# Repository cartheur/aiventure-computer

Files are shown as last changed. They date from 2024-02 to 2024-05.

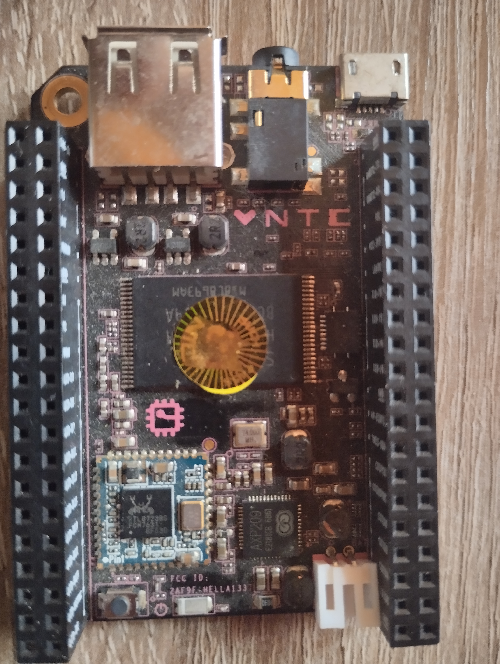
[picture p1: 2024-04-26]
chip_1_0/images/v1.0-top.jpg

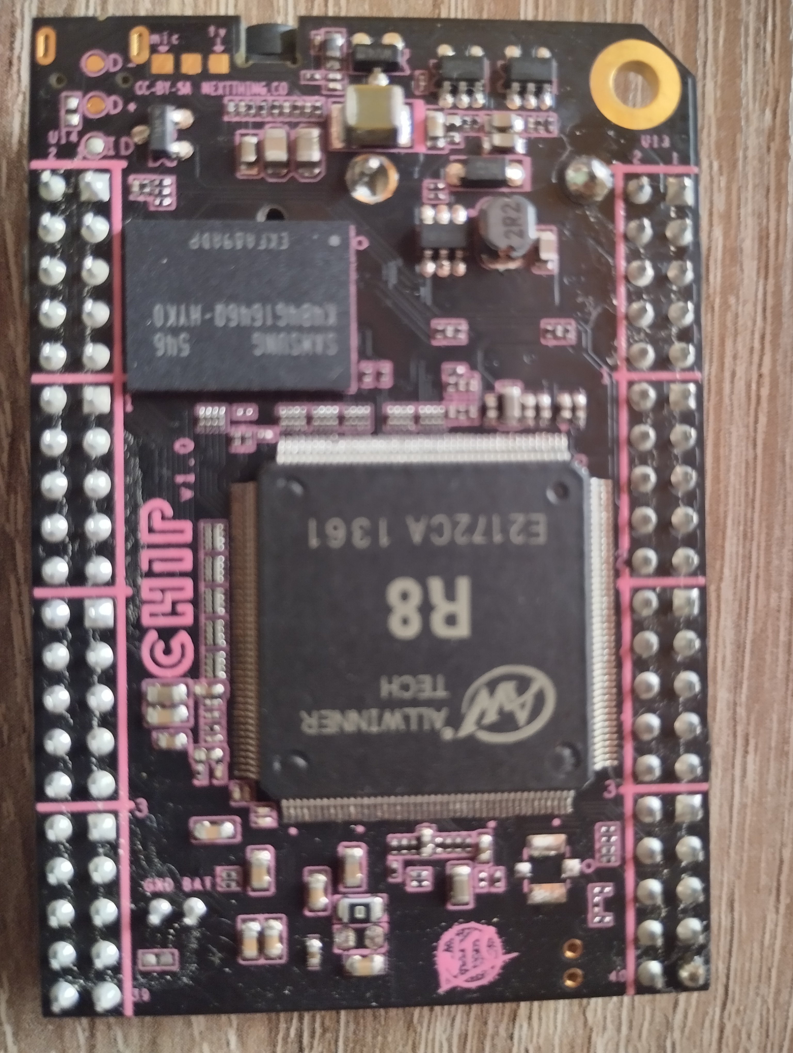
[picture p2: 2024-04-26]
chip_1_0/images/v1.0-bottom.jpg

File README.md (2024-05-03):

## aiventure-computer

The computer that currently runs our robotics platforms. As finding a replacement has been problematic for new development, can we evolve the design toward a manifestation of an aeon-class machine?

_Project Goals_

This board needs to be put into production to support [emotional](https://emotional.toys) toys products. The following changes need to be considered so that this board is brought-up to the current (2024) technological standards. The existing feature set and design experiences are listed [here](/chip_1_0/README.md).

* CPU/GPU - ARM Cortex-R82
* RAM (SDRAM) - 16 GB
    - Product tiers: 32GB, 64GB, 128GB. 256GB, 512GB 1TB
* NAND (100k writes)- 256 GB
* Pin interfaces at board level (no headers) (Requirement)
* Rechargable feature for JST connected battery retained but which allows higher-capacity batteries (Requirement)
* USB-C power, USB-B keyboard connectivity
* JST 3.5mm port 

Features nearly set for second-generation design. Getting ready.

## The target

* The target OS for the new design is Debian 12 (bookworm) with Linux kernel 6.6.23. The last kernel for the old board is version 4.4.13 according to `b149`. 
* The entire board will have to be proofed in order to obtain a rather assured estimate of the costs-per-unit of manufacture.

## The source

* The _project_ directory contains the correct <a href="http://www.orcad.com/" target="_blank">OrCAD</a> file. However, it seems to be missing footprints. They are found as a *.lbr file, which is for <a href="https://www.autodesk.com/products/eagle/free-download" target="_blank">Eagle</a>.
* It needs to be understood if the file can be opened in Altium and revised that a developer can use KiCad or EasyEDA.
* The milestone is to understand the current status and what needs to be done to prepare it for manufacturing of 500 units planned.

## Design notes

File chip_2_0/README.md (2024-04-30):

## Chip - Revision 2.0 (2024)

We are working toward a new experimental production run of this board and this folder contains the working files. Our goals will be:

* To pivot away from OrCad in favor of more accessible CAD tools
* Bring current the 2016-era components
* Produce a limited run where we will
    - Update the OS image to Debian Linux kernel 6.x
    - Introduce an autonomous ideal platform
    - Re-engineer the pin header
    - Render a different use-case for the features

### Results from analysis of current design (1.0)

Since transforming the design from OrCad to Altium, progress has been made to reveal each of the current feature-set, for import into the new production.

* The CPU is an ARM cortex8 R8 chip. It is a mid-range processor for use in deep-embedded, real time systems.
* The power management IC is APX209 which    accepts a battery and outputs several DC outputs.
* The three regulators are LP6226 which produce the 5v, 3.3v and 1.6v.
* The design contains two 40 pin LCDs. The LCDs part numbers are not defined. One of the LCDs is placed at the right side of the board and the other one is placed at the left side. Only the connectors of the LCDs can be seen in the boards.
    - The LCDs should be selected separately or According to the pinouts  of the connectors.
* There is also a remote I2C Bus expander in the design (PCF8574)
    -  In the original product there was a hat that had both banks of 40-pin headers where one could use a VGA or HDMI version to connect to an external monitor.
* There is a Bluetooth IC (8723BS) with an antenna in the board to communicate with  other devices via Bluetooth.
* To increase the addressable memory size, the design must implement the Cortex-R82 processor. It is 64-bit, 40 address bits which supports addressable memory up to 1TB.

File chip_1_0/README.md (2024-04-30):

## CHIP v1.0 Feature-Set

Features implemented on this model:

* Built-in Wi-Fi 802.11b/g/n, Bluetooth 4.0
* One USB host with type-A receptacle, one USB On-The-Go port
* Composite video and stereo audio port via mini TRRS
* Optional composite TRRS to RCA audio-video cable
* Optional VGA adapter and HDMI adapter (see Hardware extensions below)
* Open source hardware and open source software
* Unfortunately, the OrCad is _not_ open source
* Up to 45 GPIO ports
* Supports 1-Wire and I2C protocols, PWM output
* Serial console and Ethernet via USB for quick headless operation
* Power options include 5V via USB OTG, 5V via CHN pin, and by 3.7V battery
* Onboard NAND storage, 4-8 GB, pre-installed Linux OS (Debian)
* API-based firmware update
* The board is 60mm × 40mm x 15mm in size.
* The total addressable memory for the Cortex-R8 processor is 4GB.

_Analysis results_

* The schematic illustrated a number of errors which needed to be fixed. There are a multiple of errors in the pcb.
* The solution is to produce this board without any changes, but with the bugs sorted. After a round of manufacturing and software installation, resolve newly appearing bugs as a part of development of the second version that contains the updated requirements.

### Strategic initiatives

* To streamline the design process, the first version of the board is designed with Cortex-R8 and after implementing and manufacturing this version of project, increment the design to the Cortex-R82 in the second version.

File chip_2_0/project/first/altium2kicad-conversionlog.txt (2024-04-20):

Archive:  db/36068.zip
  inflating: db/36068/01 REVISION HISTORY.SchDoc  
  inflating: db/36068/02 BLOCK.SchDoc  
  inflating: db/36068/03 CPU.SchDoc  
  inflating: db/36068/04 POWER.SchDoc  
  inflating: db/36068/05 MISC.SchDoc  
  inflating: db/36068/06 SDIO WIFI&BT.SchDoc  
  inflating: db/36068/07 USB.SchDoc  
  inflating: db/36068/08 BESIDE CPU.SchDoc  
  inflating: db/36068/09 DDR3.SchDoc  
  inflating: db/36068/CHIP_v1_0.LOG  
  inflating: db/36068/CHIP_v1_0.PrjPcb  
  inflating: db/36068/CHIP_v1_0.PrjPcbStructure  
  inflating: db/36068/CHIP_v1_0_Library.SchLib  
  inflating: db/36068/01 REVISION HISTORY.~(1).SchDoc.Zip  
  inflating: db/36068/01 REVISION HISTORY.~(2).SchDoc.Zip  
  inflating: db/36068/02 BLOCK.~(1).SchDoc.Zip  
  inflating: db/36068/02 BLOCK.~(2).SchDoc.Zip  
  inflating: db/36068/03 CPU.~(1).SchDoc.Zip  
  inflating: db/36068/03 CPU.~(2).SchDoc.Zip  
  inflating: db/36068/04 POWER.~(1).SchDoc.Zip  
  inflating: db/36068/04 POWER.~(2).SchDoc.Zip  
  inflating: db/36068/05 MISC.~(1).SchDoc.Zip  
  inflating: db/36068/05 MISC.~(2).SchDoc.Zip  
  inflating: db/36068/06 SDIO WIFI&BT.~(1).SchDoc.Zip  
  inflating: db/36068/06 SDIO WIFI&BT.~(2).SchDoc.Zip  
  inflating: db/36068/07 USB.~(1).SchDoc.Zip  
  inflating: db/36068/07 USB.~(2).SchDoc.Zip  
  inflating: db/36068/08 BESIDE CPU.~(1).SchDoc.Zip  
  inflating: db/36068/08 BESIDE CPU.~(2).SchDoc.Zip  
  inflating: db/36068/09 DDR3.~(1).SchDoc.Zip  
  inflating: db/36068/09 DDR3.~(2).SchDoc.Zip  
  inflating: db/36068/CHIP_v1_0.~(1).PrjPcb.Zip  
  inflating: db/36068/CHIP_v1_0_Library.~(1).SchLib.Zip  
  inflating: db/36068/CHIP_v1_0_Library.~(2).SchLib.Zip  
  inflating: db/36068/CHIP_v1_0_Library.~(3).SchLib.Zip  
  inflating: db/36068/01 REVISION HISTORY.SchDocPreview  
  inflating: db/36068/02 BLOCK.SchDocPreview  
  inflating: db/36068/03 CPU.SchDocPreview  
  inflating: db/36068/04 POWER.SchDocPreview  
  inflating: db/36068/05 MISC.SchDocPreview  
  inflating: db/36068/06 SDIO WIFI&BT.SchDocPreview  
  inflating: db/36068/07 USB.SchDocPreview  
  inflating: db/36068/08 BESIDE CPU.SchDocPreview  
  inflating: db/36068/09 DDR3.SchDocPreview  
  inflating: db/36068/CHIP_v1_0.LOGPreview  
Loading 01 REVISION HISTORY.SchDoc

Loading 02 BLOCK.SchDoc

Loading 03 CPU.SchDoc

Loading 04 POWER.SchDoc

Loading 05 MISC.SchDoc

Loading 06 SDIO WIFI&BT.SchDoc

Loading 07 USB.SchDoc

Loading 08 BESIDE CPU.SchDoc

Loading 09 DDR3.SchDoc

Loading CHIP_v1_0_Library.SchLib

Done.
No unpacked .PcbDoc documents found. Trying to unpack it:
Loading 01 REVISION HISTORY.SchDoc

Loading 02 BLOCK.SchDoc

Loading 03 CPU.SchDoc

Loading 04 POWER.SchDoc

Loading 05 MISC.SchDoc

Loading 06 SDIO WIFI&BT.SchDoc

Loading 07 USB.SchDoc

Loading 08 BESIDE CPU.SchDoc

Loading 09 DDR3.SchDoc

Loading CHIP_v1_0_Library.SchLib

Done.
There were no unpacked PcbDoc files found.
Handling 01 REVISION HISTORY-SchDoc/Root Entry/FileHeader.dat
Unhandled Record type within: 30
Handling 02 BLOCK-SchDoc/Root Entry/FileHeader.dat
Unhandled Record type within: 30
Unhandled Record type without: 7  (#91)
Handling 03 CPU-SchDoc/Root Entry/FileHeader.dat
Unhandled Record type within: 30
Unhandled Record type within: 34
Unhandled Record type within: 34
Unhandled Record type within: 34
Unhandled Record type within: 34
Unhandled Record type within: 34
Unhandled Record type within: 34
Unhandled Record type within: 34
Unhandled Record type within: 34
Handling 04 POWER-SchDoc/Root Entry/FileHeader.dat
Unhandled Record type within: 30
Unhandled Record type within: 34
Unhandled Record type within: 34
Unhandled Record type within: 34
Unhandled Record type within: 34
Unhandled Record type within: 34
Unhandled Record type within: 34
Unhandled Record type within: 34
Unhandled Record type within: 34
Unhandled Record type within: 34
Unhandled Record type within: 34
Unhandled Record type within: 34
Unhandled Record type within: 34
Unhandled Record type within: 34
WARNING: Elliptical arcs are not supported in KiCad - creating circular arc using average radius instead
WARNING: Elliptical arcs are not supported in KiCad - creating circular arc using average radius instead
WARNING: Elliptical arcs are not supported in KiCad - creating circular arc using average radius instead
WARNING: Elliptical arcs are not supported in KiCad - creating circular arc using average radius instead
WARNING: Elliptical arcs are not supported in KiCad - creating circular arc using average radius instead
WARNING: Elliptical arcs are not supported in KiCad - creating circular arc using average radius instead
WARNING: Elliptical arcs are not supported in KiCad - creating circular arc using average radius instead
WARNING: Elliptical arcs are not supported in KiCad - creating circular arc using average radius instead
Unhandled Record type within: 34
Unhandled Record type within: 34
Unhandled Record type within: 34
WARNING: Elliptical arcs are not supported in KiCad - creating circular arc using average radius instead
WARNING: Elliptical arcs are not supported in KiCad - creating circular arc using average radius instead
WARNING: Elliptical arcs are not supported in KiCad - creating circular arc using average radius instead
WARNING: Elliptical arcs are not supported in KiCad - creating circular arc using average radius instead
WARNING: Elliptical arcs are not supported in KiCad - creating circular arc using average radius instead
WARNING: Elliptical arcs are not supported in KiCad - creating circular arc using average radius instead
WARNING: Elliptical arcs are not supported in KiCad - creating circular arc using average radius instead
WARNING: Elliptical arcs are not supported in KiCad - creating circular arc using average radius instead
Unhandled Record type within: 34
Unhandled Record type within: 34
Unhandled Record type within: 34
Unhandled Record type within: 34
Unhandled Record type within: 34
Unhandled Record type within: 34
Unhandled Record type within: 34
Unhandled Record type within: 34
Unhandled Record type within: 34
Unhandled Record type within: 34
Unhandled Record type within: 34
Unhandled Record type within: 34
Unhandled Record type within: 34
Unhandled Record type within: 34
Unhandled Record type within: 34
Unhandled Record type within: 34
Unhandled Record type within: 34
Unhandled Record type within: 34
Unhandled Record type within: 34
Unhandled Record type within: 34
WARNING: Elliptical arcs are not supported in KiCad - creating circular arc using average radius instead
WARNING: Elliptical arcs are not supported in KiCad - creating circular arc using average radius instead
WARNING: Elliptical arcs are not supported in KiCad - creating circular arc using average radius instead
WARNING: Elliptical arcs are not supported in KiCad - creating circular arc using average radius instead
WARNING: Elliptical arcs are not supported in KiCad - creating circular arc using average radius instead
WARNING: Elliptical arcs are not supported in KiCad - creating circular arc using average radius instead
WARNING: Elliptical arcs are not supported in KiCad - creating circular arc using average radius instead
WARNING: Elliptical arcs are not supported in KiCad - creating circular arc using average radius instead
Unhandled Record type within: 34
Unhandled Record type within: 34
Unhandled Record type within: 34
Unhandled Record type within: 34
Unhandled Record type within: 34
Unhandled Record type within: 34
Unhandled Record type within: 34
Unhandled Record type within: 34
Unhandled Record type within: 34
Unhandled Record type within: 34
Unhandled Record type within: 34
Unhandled Record type within: 34
Unhandled Record type within: 34
WARNING: Elliptical arcs are not supported in KiCad - creating circular arc using average radius instead
WARNING: Elliptical arcs are not supported in KiCad - creating circular arc using average radius instead
WARNING: Elliptical arcs are not supported in KiCad - creating circular arc using average radius instead
WARNING: Elliptical arcs are not supported in KiCad - creating circular arc using average radius instead
WARNING: Elliptical arcs are not supported in KiCad - creating circular arc using average radius instead
WARNING: Elliptical arcs are not supported in KiCad - creating circular arc using average radius instead
WARNING: Elliptical arcs are not supported in KiCad - creating circular arc using average radius instead
WARNING: Elliptical arcs are not supported in KiCad - creating circular arc using average radius instead
Unhandled Record type within: 34
Unhandled Record type within: 34
Unhandled Record type within: 34
Unhandled Record type within: 34
Unhandled Record type within: 34
Unhandled Record type within: 34
Unhandled Record type within: 34
Unhandled Record type within: 34
Unhandled Record type within: 34
Unhandled Record type within: 34
Unhandled Record type within: 34
Unhandled Record type within: 34
Unhandled Record type within: 34
Unhandled Record type within: 34
WARNING: Elliptical arcs are not supported in KiCad - creating circular arc using average radius instead
WARNING: Elliptical arcs are not supported in KiCad - creating circular arc using average radius instead
WARNING: Elliptical arcs are not supported in KiCad - creating circular arc using average radius instead
WARNING: Elliptical arcs are not supported in KiCad - creating circular arc using average radius instead
WARNING: Elliptical arcs are not supported in KiCad - creating circular arc using average radius instead
WARNING: Elliptical arcs are not supported in KiCad - creating circular arc using average radius instead
WARNING: Elliptical arcs are not supported in KiCad - creating circular arc using average radius instead
WARNING: Elliptical arcs are not supported in KiCad - creating circular arc using average radius instead
Unhandled Record type within: 34
Unhandled Record type within: 34
Unhandled Record type within: 34
Unhandled Record type within: 34
Unhandled Record type within: 34
WARNING: Elliptical arcs are not supported in KiCad - creating circular arc using average radius instead
WARNING: Elliptical arcs are not supported in KiCad - creating circular arc using average radius instead
WARNING: Elliptical arcs are not supported in KiCad - creating circular arc using average radius instead
WARNING: Elliptical arcs are not supported in KiCad - creating circular arc using average radius instead
WARNING: Elliptical arcs are not supported in KiCad - creating circular arc using average radius instead
WARNING: Elliptical arcs are not supported in KiCad - creating circular arc using average radius instead
WARNING: Elliptical arcs are not supported in KiCad - creating circular arc using average radius instead
WARNING: Elliptical arcs are not supported in KiCad - creating circular arc using average radius instead
Unhandled Record type within: 34
Unhandled Record type within: 34
Unhandled Record type within: 34
Unhandled Record type within: 34
Unhandled Record type within: 34
Unhandled Record type within: 34
Handling 05 MISC-SchDoc/Root Entry/FileHeader.dat
Unhandled Record type within: 30
Unhandled Record type within: 34
WARNING: Elliptical arcs are not supported in KiCad - creating circular arc using average radius instead
WARNING: Elliptical arcs are not supported in KiCad - creating circular arc using average radius instead
WARNING: Elliptical arcs are not supported in KiCad - creating circular arc using average radius instead
WARNING: Elliptical arcs are not supported in KiCad - creating circular arc using average radius instead
WARNING: Elliptical arcs are not supported in KiCad - creating circular arc using average radius instead
WARNING: Elliptical arcs are not supported in KiCad - creating circular arc using average radius instead
WARNING: Elliptical arcs are not supported in KiCad - creating circular arc using average radius instead
WARNING: Elliptical arcs are not supported in KiCad - creating circular arc using average radius instead
Unhandled Record type within: 34
Unhandled Record type within: 34
Unhandled Record type within: 34
Unhandled Record type within: 34
Unhandled Record type within: 34
Unhandled Record type within: 34
Unhandled Record type within: 34
Unhandled Record type within: 34
Unhandled Record type within: 34
Unhandled Record type within: 34
Unhandled Record type within: 34
Unhandled Record type within: 34
Unhandled Record type within: 34
Unhandled Record type within: 34
Unhandled Record type within: 34
Unhandled Record type within: 34
Unhandled Record type within: 34
Unhandled Record type within: 34
Unhandled Record type within: 34
Unhandled Record type within: 34
Unhandled Record type within: 34
Unhandled Record type within: 34
Unhandled Record type within: 34
Unhandled Record type within: 34
Unhandled Record type within: 34
Unhandled Record type within: 34
Unhandled Record type within: 34
Unhandled Record type within: 34
Unhandled Record type within: 34
Unhandled Record type within: 34
Unhandled Record type within: 34
Unhandled Record type within: 34
Unhandled Record type within: 34
Unhandled Record type within: 34
Unhandled Record type within: 34
Unhandled Record type within: 34
Unhandled Record type within: 34
Unhandled Record type within: 34
Unhandled Record type within: 34
Unhandled Record type within: 34
Unhandled Record type within: 34
Handling 06 SDIO WIFI&BT-SchDoc/Root Entry/FileHeader.dat
Unhandled Record type within: 30
Unhandled Record type within: 34
Unhandled Record type within: 34
Unhandled Record type within: 34
Unhandled Record type within: 34
Unhandled Record type within: 34
Unhandled Record type within: 34
Unhandled Record type within: 34
Unhandled Record type within: 34
Unhandled Record type within: 34
Unhandled Record type within: 34
Unhandled Record type within: 34
Unhandled Record type within: 34
Unhandled Record type within: 34
Unhandled Record type within: 34
Unhandled Record type within: 34
Unhandled Record type within: 34
Unhandled Record type within: 34
Unhandled Record type within: 34
Unhandled Record type within: 34
Unhandled Record type within: 34
Unhandled Record type within: 34
Unhandled Record type within: 34
Unhandled Record type within: 34
Unhandled Record type within: 34
Unhandled Record type within: 34
Unhandled Record type within: 34
Unhandled Record type within: 34
Unhandled Record type within: 34
Unhandled Record type within: 34
Unhandled Record type within: 34
Unhandled Record type within: 34
Handling 07 USB-SchDoc/Root Entry/FileHeader.dat
Unhandled Record type within: 30
Unhandled Record type within: 34
WARNING: Elliptical arcs are not supported in KiCad - creating circular arc using average radius instead
WARNING: Elliptical arcs are not supported in KiCad - creating circular arc using average radius instead
Unhandled Record type within: 34
Unhandled Record type within: 34
Unhandled Record type within: 34
Unhandled Record type within: 34
Unhandled Record type within: 34
Unhandled Record type within: 34
Unhandled Record type within: 34
Unhandled Record type within: 34
Unhandled Record type within: 34
Unhandled Record type within: 34
Unhandled Record type within: 34
Unhandled Record type within: 34
Unhandled Record type within: 34
Unhandled Record type within: 34
Unhandled Record type within: 34
Unhandled Record type within: 34
Unhandled Record type within: 34
Unhandled Record type within: 34
Unhandled Record type within: 34
Unhandled Record type within: 34
Unhandled Record type within: 34
Unhandled Record type within: 34
Unhandled Record type within: 34
Unhandled Record type within: 34
Unhandled Record type within: 34
Unhandled Record type within: 34
Handling 08 BESIDE CPU-SchDoc/Root Entry/FileHeader.dat
Unhandled Record type within: 30
Unhandled Record type within: 34
Unhandled Record type within: 34
Unhandled Record type within: 34
Unhandled Record type within: 34
Unhandled Record type within: 34
Unhandled Record type within: 34
Unhandled Record type within: 34
Unhandled Record type within: 34
Unhandled Record type within: 34
Unhandled Record type within: 34
Unhandled Record type within: 34
Unhandled Record type within: 34
Unhandled Record type within: 34
Unhandled Record type within: 34
Unhandled Record type within: 34
Unhandled Record type within: 34
Unhandled Record type within: 34
Unhandled Record type within: 34
Unhandled Record type within: 34
Unhandled Record type within: 34
Unhandled Record type within: 34
Unhandled Record type within: 34
Unhandled Record type within: 34
Unhandled Record type within: 34
Unhandled Record type within: 34
Unhandled Record type within: 34
Unhandled Record type within: 34
Unhandled Record type within: 34
Unhandled Record type within: 34
Unhandled Record type within: 34
Unhandled Record type within: 34
Unhandled Record type within: 34
Unhandled Record type within: 34
Unhandled Record type within: 34
Unhandled Record type within: 34
Unhandled Record type within: 34
Unhandled Record type within: 34
Unhandled Record type within: 34
Unhandled Record type within: 34
Unhandled Record type within: 34
Unhandled Record type within: 34
Unhandled Record type within: 34
Unhandled Record type within: 34
Unhandled Record type within: 34
Unhandled Record type within: 34
Unhandled Record type within: 34
Unhandled Record type within: 34
Unhandled Record type within: 34
Unhandled Record type within: 34
Unhandled Record type within: 34
Unhandled Record type within: 34
Unhandled Record type within: 34
Handling 09 DDR3-SchDoc/Root Entry/FileHeader.dat
Unhandled Record type within: 30
Unhandled Record type within: 34
Unhandled Record type within: 34
Unhandled Record type within: 34
Unhandled Record type within: 34
Unhandled Record type within: 34
Unhandled Record type within: 34
Unhandled Record type within: 34
Unhandled Record type within: 34
Unhandled Record type within: 34
Unhandled Record type within: 34
Unhandled Record type within: 34
Unhandled Record type within: 34
Unhandled Record type within: 34
Unhandled Record type within: 34
Unhandled Record type within: 34
Unhandled Record type within: 34
Unhandled Record type within: 34
Unhandled Record type within: 34
Unhandled Record type within: 34
Unhandled Record type within: 34
Unhandled Record type within: 34
Unhandled Record type within: 34
Unhandled Record type within: 34
Unhandled Record type within: 34
Unhandled Record type within: 34
Unhandled Record type within: 34
Unhandled Record type within: 34
Unhandled Record type within: 34
Unhandled Record type within: 34
Unhandled Record type within: 34
Unhandled Record type within: 34
Unhandled Record type within: 34
Unhandled Record type within: 34
Unhandled Record type within: 34
Unhandled Record type within: 34
Unhandled Record type within: 34
Unhandled Record type within: 34
Unhandled Record type within: 34
Unhandled Record type within: 34
Unhandled Record type within: 34
Unhandled Record type within: 34
Unhandled Record type within: 34
Unhandled Record type within: 34
Unhandled Record type within: 34
Unhandled Record type within: 34
Handling CHIP_v1_0_Library-SchLib/Root Entry/FileHeader.dat
Handling 01 REVISION HISTORY.SchDoc
Handling 02 BLOCK.SchDoc
Handling 03 CPU.SchDoc
Handling 04 POWER.SchDoc
Handling 05 MISC.SchDoc
Handling 06 SDIO WIFI&BT.SchDoc
Handling 07 USB.SchDoc
Handling 08 BESIDE CPU.SchDoc
Handling 09 DDR3.SchDoc

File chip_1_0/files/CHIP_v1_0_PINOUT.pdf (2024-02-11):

GND | 1 | 2 | CHG-IN | | GND | 1 | 2 | VCC-5V
VCC-5V | 3 | 4 | GND | | UART1-TX | 3 | 4 | HPL
VCC-3V3 | 5 | 6 | TS | | UART1-RX | 5 | 6 | HPCOM
VCC-1V8 | 7 | 8 | BAT | | FEL | 7 | 8 | HPR
TWI1-SDA | 9 | 10 | PWRON | was LRADC> | VCC-3V3 | 9 | 10 | MICM
TWI1-SCK | 11 | 12 | GND | was GND> | LRADC | 11 | 12 | MICIN1
X1 | 13 | 14 | X2 | | XIO-P0 | 13 | 14 | XIO-P1
Y1 | 15 | 16 | Y2 | | XIO-P2 | 15 | 16 | XIO-P3
LCD-D2 | 17 | 18 | PWM0 | | XIO-P4 | 17 | 18 | XIO-P5
LCD-D4 | 19 | 20 | LCD-D3 | | XIO-P6 | 19 | 20 | XIO-P7
LCD-D6 | 21 | 22 | LCD-D5 | | GND | 21 | 22 | GND
LCD-D10 | 23 | 24 | LCD-D7 | | AP-EINT1 | 23 | 24 | AP-EINT3
LCD-D12 | 25 | 26 | LCD-D11 | | TWI2-SDA | 25 | 26 | TWI2-SCK
LCD-D14 | 27 | 28 | LCD-D13 | | CSIPCK | 27 | 28 | CSICK
LCD-D18 | 29 | 30 | LCD-D15 | | CSIHSYNC | 29 | 30 | CSIVSYNC
LCD-D20 | 31 | 32 | LCD-D19 | | CSID0 | 31 | 32 | CSID1
LCD-D22 | 33 | 34 | LCD-D21 | | CSID2 | 33 | 34 | CSID3
LCD-CLK | 35 | 36 | LCD-D23 | | CSID4 | 35 | 36 | CSID5
LCD-VSYNC | 37 | 38 | LCD-HSYNC | | CSID6 | 37 | 38 | CSID7
GND | 39 | 40 | LCD-DE | | GND | 39 | 40 | GND

Use square pad

## C.H.I.P. (v1.0) PINOUT

U13 | U14

New Pin Location vs. v0.21

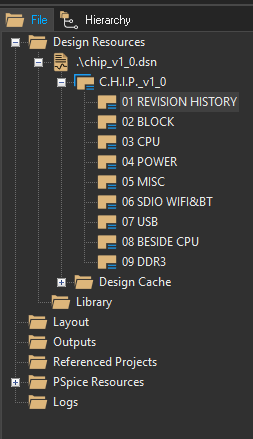
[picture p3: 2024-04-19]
chip_2_0/catalogue/design root/Design root.png

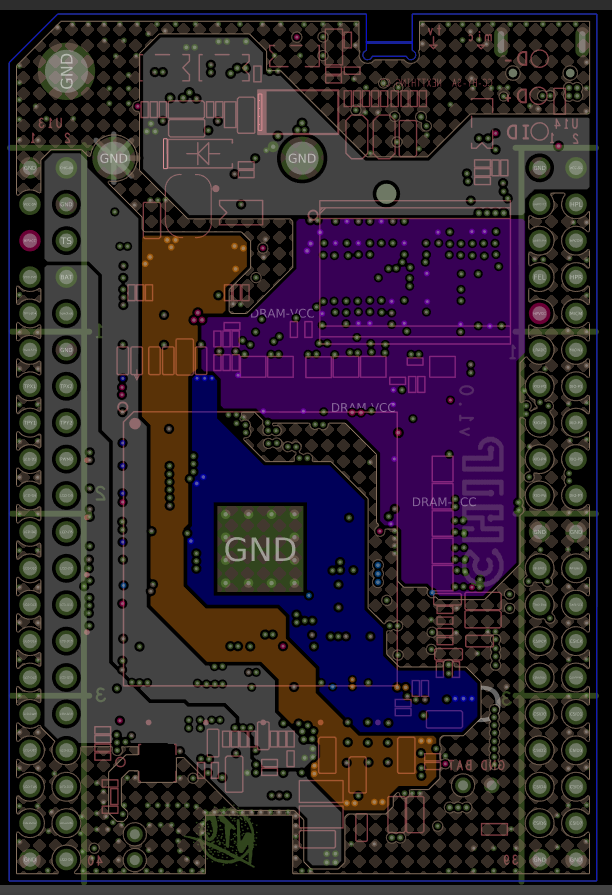
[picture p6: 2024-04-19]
chip_2_0/catalogue/PCB/Vcc layer.png

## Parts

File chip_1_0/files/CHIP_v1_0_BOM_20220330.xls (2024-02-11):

*********************************************************************************************************************************************
the cartheur company
docs.cartheur.ai
*********************************************************************************************************************************************
PCBA BOM
Model |  |  | C.H.I.P.
Version |  |  | v1.0
BOM Revision |  |  | V1_0_20220330
Date |  |  | 2022-03-30
 | Description | QTY(QPA) | Location(refernece) | Type(DIP/SMT)
1 | IC CPU R8 TQFP177 | 1 | U1 | SMT
2 | IC PMU AXP209 QFN49_0_4H0_8A | 1 | U3 | SMT
3 | IC IO EXTEND PCF8574ARGYR QFN20-PT0_5-3_65X4_65H1A | 1 | U27 | SMT
4 | IC CONTINUOUS CURRENT LPW5210 SOT23_5H14A | 2 | U10,U15 | SMT
5 | IC DC-DC LP3220SAB5F SOT23-5 | 2 | U4,U12 | SMT
6 | IC DC-DC LP6226B6F SOT23-6 | 1 | U11 | SMT
7 | IC NAND FLASH X8 TSOP-48H1_2A | 1 | U30 | SMT
8 | IC DDR3-FBGA96 FBGA96C80P9X13 | 1 | U29 | SMT
9 | SMD MODULE WIFI 8723BS QFN44-AP6476-12X12H1_6A | 1 | U9 | SMT
10 | SMD CRYSTAL 24MHz ±10ppm 18pF SMD322524ECFP1F 3.2*2.5mm | 1 | X1 | SMT
11 | SMD INDUCTOR 1.8uH 0603 | 1 | L9 | SMT
12 | SMD INDUCTOR 2.2uH DCR<0.1R-1.7A 3518 | 6 | L2,L3,L4,L5,L6,L8 | SMT
13 | SMD DIODE IN5819 SOD123FL | 1 | D16 | SMT
14 | SMD DIODE BAT54S SOT-23 | 1 | D18 | SMT
15 | SMD LED 0603 white color (e.g. Everlight QTLP603CIWTR or similar) | 1 | D2 | SMT
16 | SMD LED EC01-0603QRC-E-Ag pink color (e.g. lowcost versions of Panasonic LNJP12X8ARA or similar) | 1 | D1 | SMT
17 | CHIP WiFi/Bluetooch Ceramic Antenna AA055 3.2X1.6X0.5 | 1 | ANT1 | SMT
18 | SMD TRANSISTOR MMBT3904 NPN SOT-23 | 1 | Q4 | SMT
19 | SMD C-MOS N-channel BSN20 SOT-23 | 1 | Q11 | SMT
20 | DIP CONNECTOR CON2X20-PT2_54-5_2X31_2H2A (40PIN母座 双排，间距2.54MM） | 2 | U13,U14 | DIP
21 | DIP CONNECTOR CON2-PT2_54H7_1A(2PIN母座，间距2.54MM） | 1 | J1 | DIP
22 | SMD JACK MICRO USB A01SB141BH2_4A | 1 | J4 | SMT
23 | SMD JACK USB_AF-011Z_45H5_2A | 1 | J5 | DIP
24 | SMD JACK EARPHONE PJ-033SMTH4A | 1 | J11 | SMT
25 | SMD KEY SW_4P_TC3061B/IT-1100AE （2PIN，间距4.4MM，有两个定位孔) | 1 | SW1 | SMT
26 | CAP 0201 18pF 16V NPO | 2 | C1,C5 | SMT
27 | CAP 0201 22pF 16V NPO | 1 | C53 | SMT
28 | CAP 0201 47pF 16V NPO | 2 | C67,C73 | SMT
29 | CAP 0201 100pF 16V NPO | 1 | C294 | SMT
30 | CAP 0201 270pF 16V NPO | 1 | C55 | SMT
31 | CAP 0201 330pF 16V NPO | 1 | C56 | SMT
32 | CAP 0201 102 16V ±20% | 7(-1) | C15,C20,C165,C173,C174,C175,C176 | SMT
33 | CAP 0201 2.2P 16V ±0.1pF | 1 | C51 | SMT
34 | CAP 0201 104 10V ±20% | 41 | C33,C34,C35,C36,C54,C58,C64,C69,C72,C81,C82,C83,C84,C90,C91,C92,C93,C94,C95,C96,C102,C103,C104,C105,C106,C148,C151,C152,C166,C168,C170,C172,C189,C190,C191,C192,C193,C194,C295,C297,C298 | SMT
35 | CAP 0402 105 10V ±20% | 25 | C9,C22,C24,C26,C37,C49,C145,C150,C153,C154,C158,C159,C160,C161,C164,C179,C180,C181,C182,C183,C184,C185,C186,C296,C299 | SMT
36 | CAP 0603 4.7uF 10V ±20% | 19 (-2) | C10,C11,C12,C25,C27,C28,C29,C50,C59,C65,C66,C68,C70,C71,C74,C76,C142,C169,C188 | SMT
37 | CAP 0603 10uF 10V ±20% | 17 (-1) | C13,C14,C16,C17,C18,C19,C21,C32,C45,C57,C75,C77,C149,C157,C167,C177,C178 | SMT
38 | CAP 0805 22uF 10V ±20% | 2 | C78,C79 | SMT
39 | SMD RCA 0201-4 0ΩX4 1/20W | 2 | RN1,RN2 | SMT
40 | SMD RCA 0201-4 24ΩX4 1/20W | 1 | RN30 | SMT
41 | SMD RCA 0201-4 33ΩX4 1/20W | 10 | RN20,RN21,RN22,RN23,RN24,RN25,RN26,RN27,RN28,RN29 | SMT
42 | RESISTOR 0201 24Ω 1/20W ±5% | 6 | R68,R100,R101,R420,R421,R422 | SMT
43 | RESISTOR 0201 75Ω 1/20W ±5% | 1 | R60 | SMT
44 | RESISTOR 0201 240Ω 1/16W ±1% | 2 | R71,R94 | SMT
45 | RESISTOR 0201 1KΩ 1/20W ±5% | 5 | R8,R83,R86,R102,R113 | SMT
46 | RESISTOR 0201 1.5KΩ 1/20W ±5% | 1 | R192 | SMT
47 | RESISTOR 0201 2KΩ 1/16W ±1% | 4 | R89,R90,R91,R416 | SMT
48 | RESISTOR 0201 2.2KΩ 1/20W ±5% | 7 | R1,R2,R3,R4,R6,R18,R103 | SMT
49 | RESISTOR 0201 10KΩ 1/20W ±5% | 10 | NSR3,R10,R11,R55,R56,R70,R87,R130,R131,R206 | SMT
50 | RESISTOR 0201 33KΩ 1/20W ±5% | 5 | R48,R49,R51,R52,R53 | SMT
51 | RESISTOR 0201 47KΩ 1/20W ±5% | 2 | R16,R17 | SMT
52 | RESISTOR 0201 100KΩ 1/20W ±5% | 3 | R65,R66,R105 | SMT
53 | RESISTOR 0201 510KΩ 1/20W ±5% | 1 | R74 | SMT
54 | RESISTOR 0201 1MΩ 1/20W ±5% | 1 | R88 | SMT
55 | RESISTOR 0201 0Ω 1/20W ±5% | 11 | R12,R39,R40,R41,R43,R46,R84,R85,R122,R414 | SMT
56 | RESISTOR 0402 1Ω 1/16W ±5% | 2 | R9,R82 | SMT
57 | RESISTOR 0201 2KΩ 1/16W ±5% | 1 | R20 | SMT
58 | RESISTOR 0805 0Ω 1/8W | 1 | R81 | SMT
59 | RESISTOR 0201 6.8KΩ 1/20W ±1% | 2 | OR4,R75 | SMT
60 | RESISTOR 0201 27KΩ 1/20W ±1% | 1 | R57 | SMT
61 | RESISTOR 0201 100KΩ 1/20W ±1% | 2 | R14,R78 | SMT
62 | RESISTOR 0201 150KΩ 1/20W ±1% | 1 | R15 | SMT
63 | RESISTOR 0201 200KΩ 1/20W ±1% | 3 | R13,R54,R121 | SMT
64 | RESISTOR 0201 442KΩ 1/16W ±1% | 1 | R79 | SMT
65 | RESISTOR 0805 0.03Ω 1/8W ±1% | 1 | R7 | SMT
66 | CAP 1210 100uF 10V ±20% | 1 | C146 | SMT
67 | CAP 0201 1.5pF 16V ±0.1pF | 1 | C47 | SMT
68 | CAP 0201 3.3pF 16V ±0.1pF | 1 | R45 | SMT

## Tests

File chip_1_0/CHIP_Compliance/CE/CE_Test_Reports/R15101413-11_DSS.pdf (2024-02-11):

Note: This test report is prepared for the customer shown above and for the device described herein. It may not be duplicated or used in part without prior written consent from Bay Area Compliance Laboratories Corp. This report must not be used by the customer to claim product certification, approval, or endorsement by A2LA* or any agency of the Federal Government.
* This report may contain data that are not covered by the A2LA accreditation and are marked with an asterisk “*” (Rev.3)

# EN 300 328 V1.9.1 (2015-02)

# TEST AND MEASUREMENT REPORT

### For

# Next Thing Company

1940 Union St #32,

### Oakland, CA 94607, USA

# Model: HELLA1337

Report Type: Original Report | Product Type: C.H.I.P Computer
Prepared By | Jin Yang Test Engineer
Report Number | R15101413-11 DSS
Report Date | 2015-12-29
Reviewed By | Bo Li RF Supervisor
| Bay Area Compliance Laboratories Corp. 1274 Anvilwood Avenue, Sunnyvale, CA 94089 Tel: (408) 732-9162 Fax: (408) 732 9164

Next Thing Company | Model Number: HELLA1337
Report Number:R15101413-11 DSS | Page 2 of 67 | EN 300 328 V1.9.1

## TABLE OF CONTENTS

### 6 EN 300 328 §4.3.1.4 DWELL TIME, MINIMUM FREQUENCY OCCUPATION AND HOPPING

Report Number:R15101413-11 DSS | Page 3 of 67 | EN 300 328 V1.9.1

Report Number:R15101413-11 DSS | Page 4 of 67 | EN 300 328 V1.9.1

DOCUMENT REVISION HISTORY

Revision Number | Report Number | Description of Revision | Date of Revision
0 | R15101413-11 DSS | Original Report | 2015-12-29

Report Number:R15101413-11 DSS | Page 5 of 67 | EN 300 328 V1.9.1

## 1 General Information

### 1.1 Product Description for Equipment Under Test (EUT)

This test and measurement report was prepared on behalf of Next Thing, Co., and their product C.H.I. P Computer, model: HELLA1337 or the “EUT” as referred to in this report. It is a computer, contains 2.4GHz 802.11b/g/n and Bluetooth 4.0 dual modes.

### 1.2 Mechanical Description of EUT

The EUT measures approximately 60 mm (L) x 41 mm (W) x 10 mm (H) and weighs 23.5 g.

The test data gathered are from typical production sample, serial number: R15101413-01 assigned by BACL.

### 1.3 Objective

The following type approved report is prepared on behalf Next Thing, Co.. in accordance with EN 300 328 V1.9.1(2015-02), Electromagnetic compatibility and Radio spectrum Matters (ERM); Wideband Transmission systems; data transmission equipment operating in the 2.4 GHz ISM band and using spread spectrum modulation techniques.

The objective is to determine compliance with EN 300 328 V1.9.1 (2015-02), Electromagnetic compatibility and Radio spectrum Matters (ERM) for Bluetooth and WLAN portion.

In order to determine compliance, the manufacturer or a contracted laboratory makes measurements and takes the necessary steps to ensure that the equipment complies with the appropriate technical standards.

Maintenance of compliance is the responsibility of the manufacturer. Any modification of the product maybe which result in lowering the immunity should be checked to ensure compliance has been maintained (i.e., printed circuit board layout changes, different line filter, different power supply, harnessing and/or I/O cable changes, etc.).

### 1.4 Related Submittal(s)/Grant(s)

No Related Submittals.

### 1.5 Test Methodology

All measurements contained in this report were conducted with EN 300 328 V1.9.1 (2015-02), Electromagnetic compatibility and Radio spectrum Matters (ERM); Wideband Transmission systems; Data transmission equipment operating in the 2,4 GHz ISM band and using spread spectrum modulation techniques

All tests were performed at Bay Area Compliance Laboratories Corp.

### 1.6 Measurement Uncertainty

All measurements involve certain levels of uncertainties, especially in the field of EMC. The factors contributing to uncertainties are spectrum analyzer, cable loss, antenna factor calibration, antenna directivity, antenna factor variation with height, antenna phase center variation, antenna factor frequency interpolation, measurement distance variation, site imperfections, mismatch (average), and system repeatability.

Based on NIS 81, The Treatment of Uncertainty in EMC Measurements, the values ranging from +2.0 dB for Conducted Emissions tests and +4.0 dB for Radiated Emissions tests are the most accurate estimates pertaining to uncertainty of EMC measurements at BACL Corp.

Report Number:R15101413-11 DSS | Page 6 of 67 | EN 300 328 V1.9.1

### 1.7 Test Facility

Bay area compliance Laboratories Corp. (BACL) is:
1- An independent Commercial Test Laboratory accredited to ISO 17025:2005 by A2LA, in the fields of: Electromagnetic Compatibility & Telecommunications covering Emissions, Immunity, Radio, RF Exposure, Safety and Telecom. This includes NEBS (Network Equipment Building System), Wireless RF, Telecommunications Terminal Equipment (TTE); Network Equipment; Information Technology Equipment (ITE); Medical Electrical Equipment; Industrial, Commercial, and Medical Test Equipment; Professional Audio and Video Equipment; Electronic (Digital) Products; Industrial and Scientific Instruments; Cabled Distribution Systems and Energy Efficiency Lighting.

2- An ENERGY STAR Recognized Laboratory, for the LM80 Testing, a wide variety of Luminares and Computers.

3- A NIST Designated Phase-I and Phase-II CAB including: ACMA (Australian Communication and Media Authority), BSMI (Bureau of Standards, Metrology and Inspection of Taiwan), IDA (Infocomm Development Authority of Singapore), IC(Industry Canada), Korea ( Ministry of Communications Radio Research Laboratory), NCC (Formerly DGT; Directorate General of Telecommunication of Chinese Taipei) OFTA (Office of the Telecommunications Authority of Hong Kong), Vietnam, VCCI - Voluntary Control Council for Interference of Japan and a designated EU CAB (Conformity Assessment Body) (Notified Body) for the EMC and R&TTE Directives.

4- A Product Certification Body accredited to ISO Guide 65:1996 by A2LA to certify:
1- Unlicensed, Licensed radio frequency devices and Telephone Terminal Equipment for the FCC. Scope A1, A2, A3, A4, B1, B2, B3, B4 & C.
2. Radio Standards Specifications (RSS) in the Category I Equipment Standards List and All Broadcasting Technical Standards (BETS) in Category I Equipment Standards List for Industry Canada.
3. Radio Communication Equipment for Singapore.
4. Radio Equipment Specifications, GMDSS Marine Radio Equipment Specifications, and Fixed Network Equipment Specifications for Hong Kong.
5. Japan MIC Telecommunication Business Law (A1, A2) and Radio Law (B1, B2 and B3).
6. Audio/Video, Battery Charging Systems, Computers, Displays, Enterprise Servers, Imaging Equipment, Set-Top Boxes, Telephony, Televisions, Ceiling Fans, CFLs (Including GU24s),Decorative Light Strings, Integral LED Lamps, Luminaires, Residential Ventilating Fans.

The test site used by BACL Corp. to collect radiated and conducted emissions measurement data is located at its facility in Sunnyvale, California, USA.

The test site at BACL Corp. has been fully described in reports submitted to the Federal Communication Commission (FCC) and Voluntary Control Council for Interference (VCCI). The details of these reports have been found to be in compliance with the requirements of Section 2.948 of the FCC Rules on February 11 and December 10, 1997, and Article 8 of the VCCI regulations on December 25, 1997. The test site also complies with the test methods and procedures set forth in CISPR 22:2008 §10.4 for measurements below 1 GHz and §10.6 for measurements above 1 GHz as well as ANSI C63.4-2014, ANSI C63.4-2009, TIA/EIA-603 & CISPR 24:2010.

The Federal Communications Commission and Voluntary Control Council for Interference have the reports on file and they are listed under FCC registration number: 90464 and VCCI Registration No.: A-0027. The test site has been approved by the FCC and VCCI for public use and is listed in the FCC Public Access Link (PAL) database.

Additionally, BACL Corp. is an American Association for Laboratory Accreditation (A2LA) accredited laboratory (Lab Code 3297-02). The current scope of accreditations can be found at http://www.a2la.org/scopepdf/3297-02.pdf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

Report Number:R15101413-11 DSS | Page 7 of 67 | EN 300 328 V1.9.1

## 2 EUT TEST CONFIGURATION

### 2.1 Justification

The EUT was configured for testing according to EN 300 328 V1.9.1.

### 2.2 EUT Exercise Software

The test utility used is UART Terminal (RS-232) provided by Next Thing, Co., the software was verified by Jin Yang to comply with the standard requirements being tested against.

### 2.3 Equipment Modifications

A SMA port was attached to the output signal before the antenna of the EUT to perform conducted measurements.

### 2.4 Local Support Equipment

Manufacturer | Description | Model No.
Acer | Laptop | ZHK

### 2.5 EUT Internal Configuration Details

Manufacturer | Description | Model
Realtek Semiconductor Corp | WIFI/BT Module | RTL8723BS
Allwinner Technology | Soc | R8

### 2.6 Support Equipment

Manufacturer | Description | Model
Apple | USB Power Adapter | A1357
Asian Power Devices, Inc | AC Adapter | WB-10E05FU

### 2.7 Interface Ports and Cabling

Cable Description | Length (m) | To | From
USB Cable | <1M | Laptop | EUT
RF Cable | <1M | EUT | PSA

Report Number:R15101413-11 DSS | Page 8 of 67 | EN 300 328 V1.9.1

## 3 Summary of Test Results

EN 300 328 V1.9.1 | Description Of Tests | Results
Section 4.3.1.2 | RF Output Power | Compliant
Section 4.3.1.3 | Duty Cycle, TX-sequence, TX-gap | N/A¹
Section 4.3.1.4 | Dwell time, Minimum frequency occupation | Compliant
Section 4.3.1.5 | Hopping Frequency Separation | Compliant
Section 4.3.1.6 | MU factor | N/A¹
Section 4.3.1.7 | Adaptivity | N/A²
Section 4.3.1.8 | Occupied Channel Bandwidth | Compliant
Section 4.3.1.9 | TX Unwanted Emissions in the out-of-band Domain | Compliant
Section 4.3.1.10 | TX Unwanted Emissions in the spurious Domain | Compliant
Section 4.3.1.11 | Receiver Spurious Emissions | Compliant
Section 4.3.1.12 | Receiver Blocking | N/A²
Section 4.3.1.13 | Geo-location capability | N/A³

N/A¹
: EUT is an adaptive device
N/A²
: The power of EUT is lower than 10 dBm (EIRP) N/A³
: This EUT does not have the Geo-location capability

## 4 EN 300 328 §4.3.1.8 – Occupied Channel Bandwidth

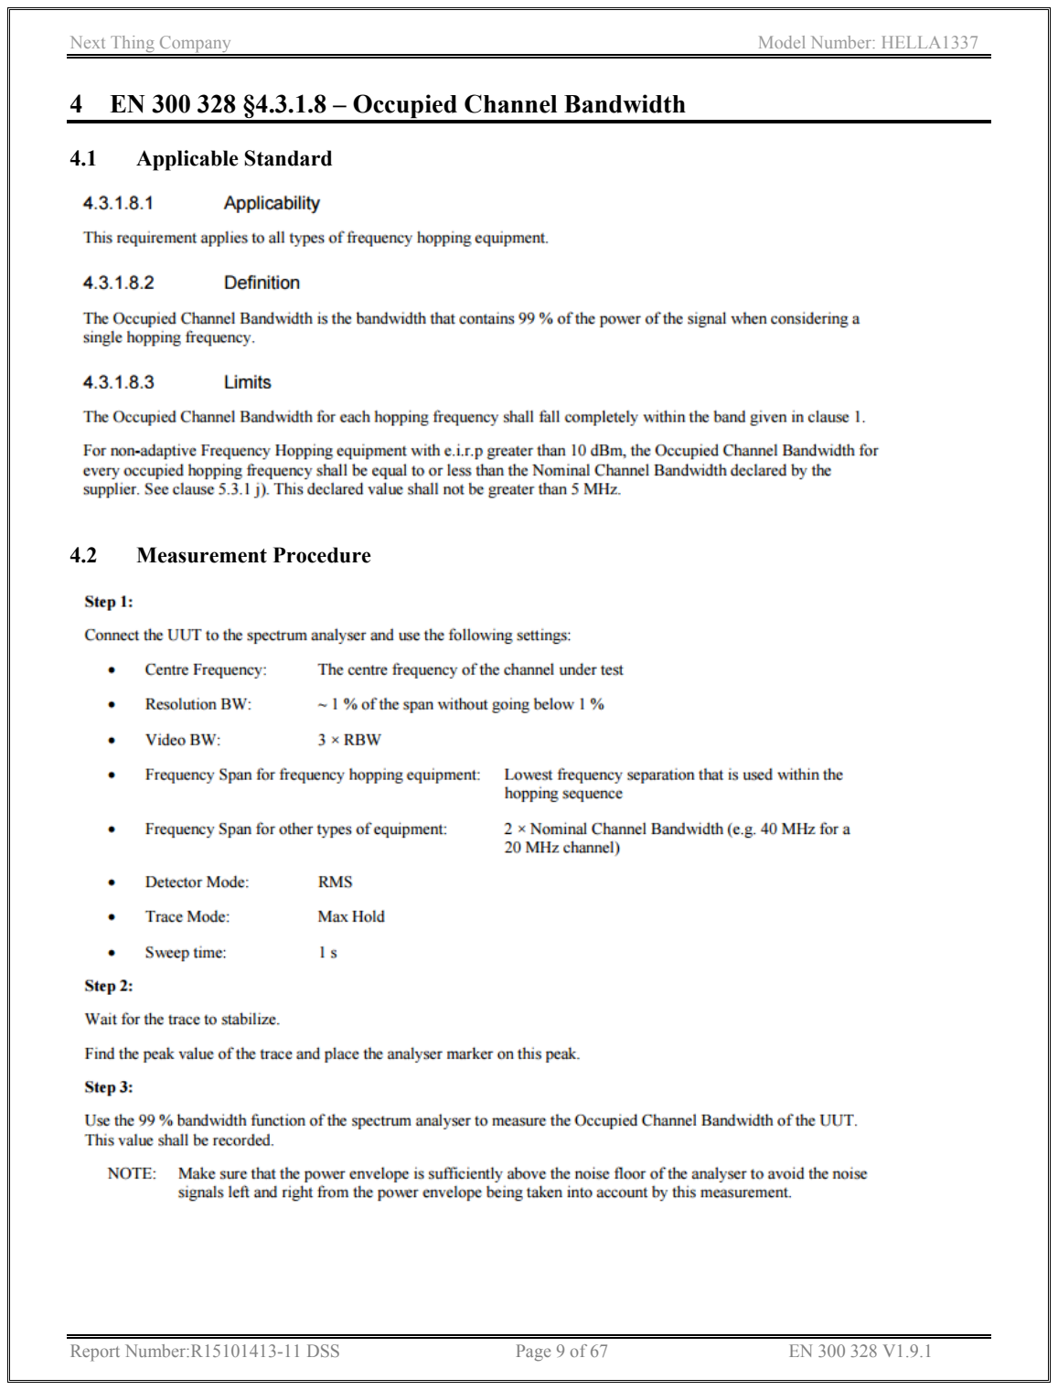
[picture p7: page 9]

Report Number:R15101413-11 DSS | Page 9 of 67 | EN 300 328 V1.9.1

### 4.1 Applicable Standard

### 4.2 Measurement Procedure

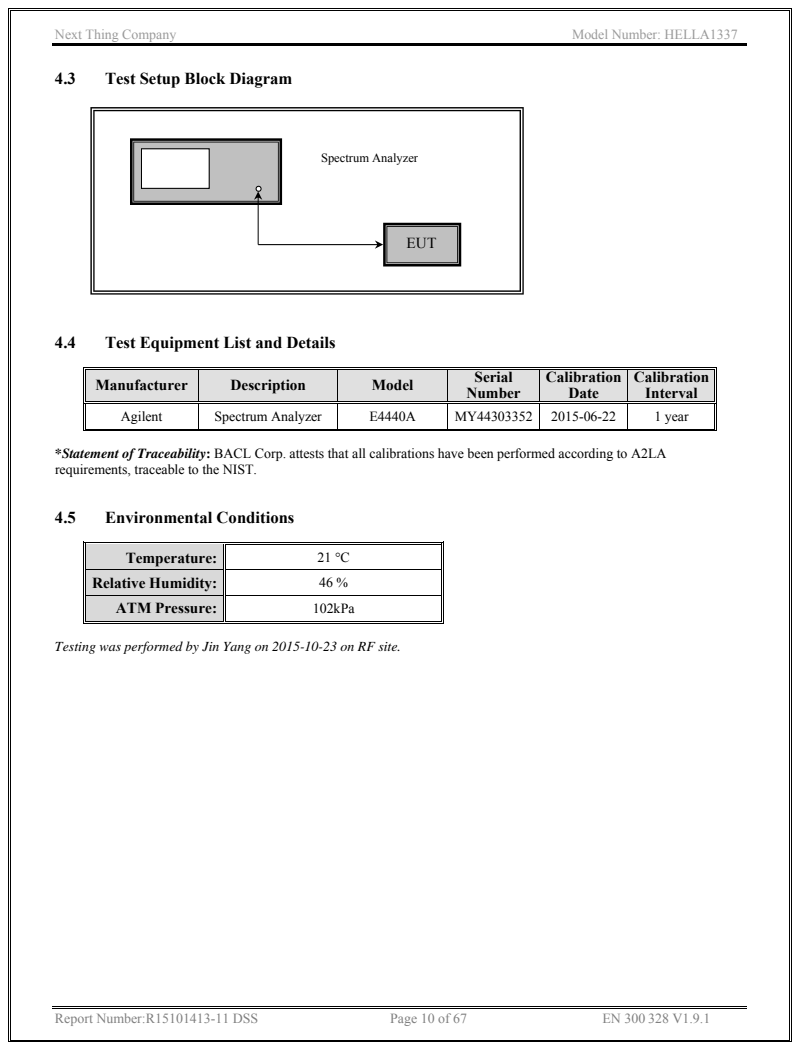
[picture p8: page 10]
Report Number:R15101413-11 DSS; Page 10 of 67; 4.5 Environmental Conditions; Spectrum Analyzer; EUT

4.3 Test Setup Block Diagram

4.4 Test Equipment List and Details

Manufacturer | Description | Model | Serial Number | Calibration Date | Calibration Interval

Agilent | Spectrum Analyzer | E4440A | MY44303352 | 2015-06-22 | 1 year

*Statement of Traceability: BACL Corp. attests that all calibrations have been performed according to A2LA
requirements, traceable to the NIST.

Temperature: | 21 °C
Relative Humidity: | 46 %
ATM Pressure: | 102kPa

Testing was performed by Jin Yang on 2015-10-23 on RF site.

Report Number:R15101413-11 DSS | Page 11 of 67 | EN 300 328 V1.9.1

### 4.6 Test Results

Bluetooth:

GFSK mode

Channel | Frequency (MHz) | Occupied Channel Bandwidth (MHz) | Limit | Results
Low | 2402 | 0.8949594 | 2400-2483.5MHz | Pass
Middle | 2441 | 0.8985763 | 2400-2483.5MHz | Pass
High | 2480 | 0.9003339 | 2400-2483.5MHz | Pass

Π/4-DQPSK mode

Channel | Frequency (MHz) | Occupied Channel Bandwidth (MHz) | Limit | Results
Low | 2402 | 1.1894 | 2400-2483.5MHz | Pass
Middle | 2441 | 1.1902 | 2400-2483.5MHz | Pass
High | 2480 | 1.1910 | 2400-2483.5MHz | Pass

8PSK mode

Channel | Frequency (MHz) | Occupied Channel Bandwidth (MHz) | Limit | Results
Low | 2402 | 1.1797 | 2400-2483.5MHz | Pass
Middle | 2441 | 1.1807 | 2400-2483.5MHz | Pass
High | 2480 | 1.1808 | 2400-2483.5MHz | Pass

Please refer to the following plots

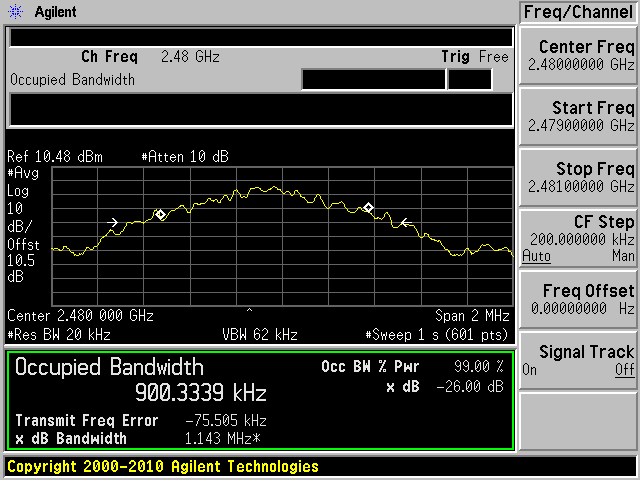
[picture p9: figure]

Report Number:R15101413-11 DSS | Page 12 of 67 | EN 300 328 V1.9.1

GFSK

Low Channel 2402 MHz | Middle Channel 2441 MHz

High Channel 2480 MHz

Report Number:R15101413-11 DSS | Page 13 of 67 | EN 300 328 V1.9.1

Π/4-DQPSK

Low Channel 2402 MHz | Middle Channel 2441 MHz

High Channel 2480 MHz

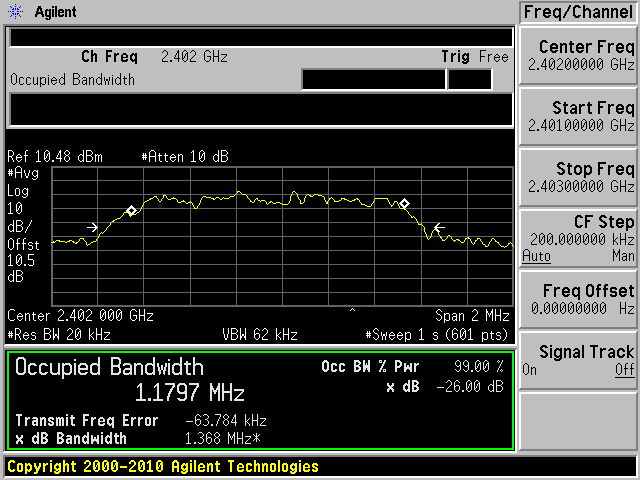
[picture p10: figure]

Report Number:R15101413-11 DSS | Page 14 of 67 | EN 300 328 V1.9.1

8PSK

Low Channel 2402 MHz | Middle Channel 2441 MHz

High Channel 2480 MHz

## 5 EN 300 328 §4.3.1.2 – RF Output Power

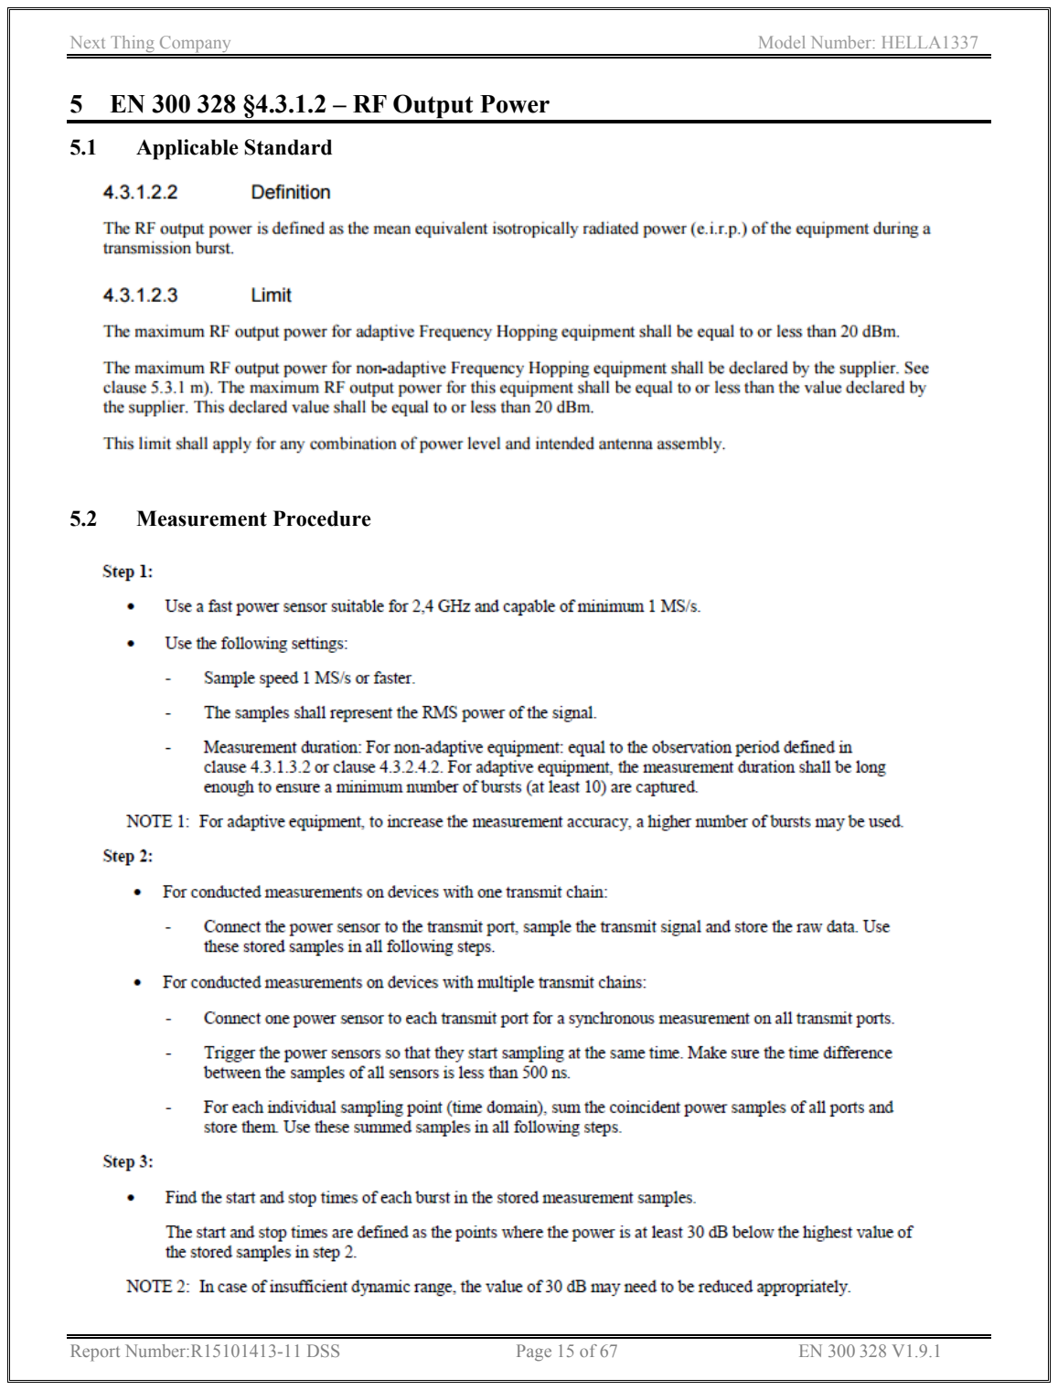
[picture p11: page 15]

Report Number:R15101413-11 DSS | Page 15 of 67 | EN 300 328 V1.9.1

### 5.1 Applicable Standard

### 5.2 Measurement Procedure

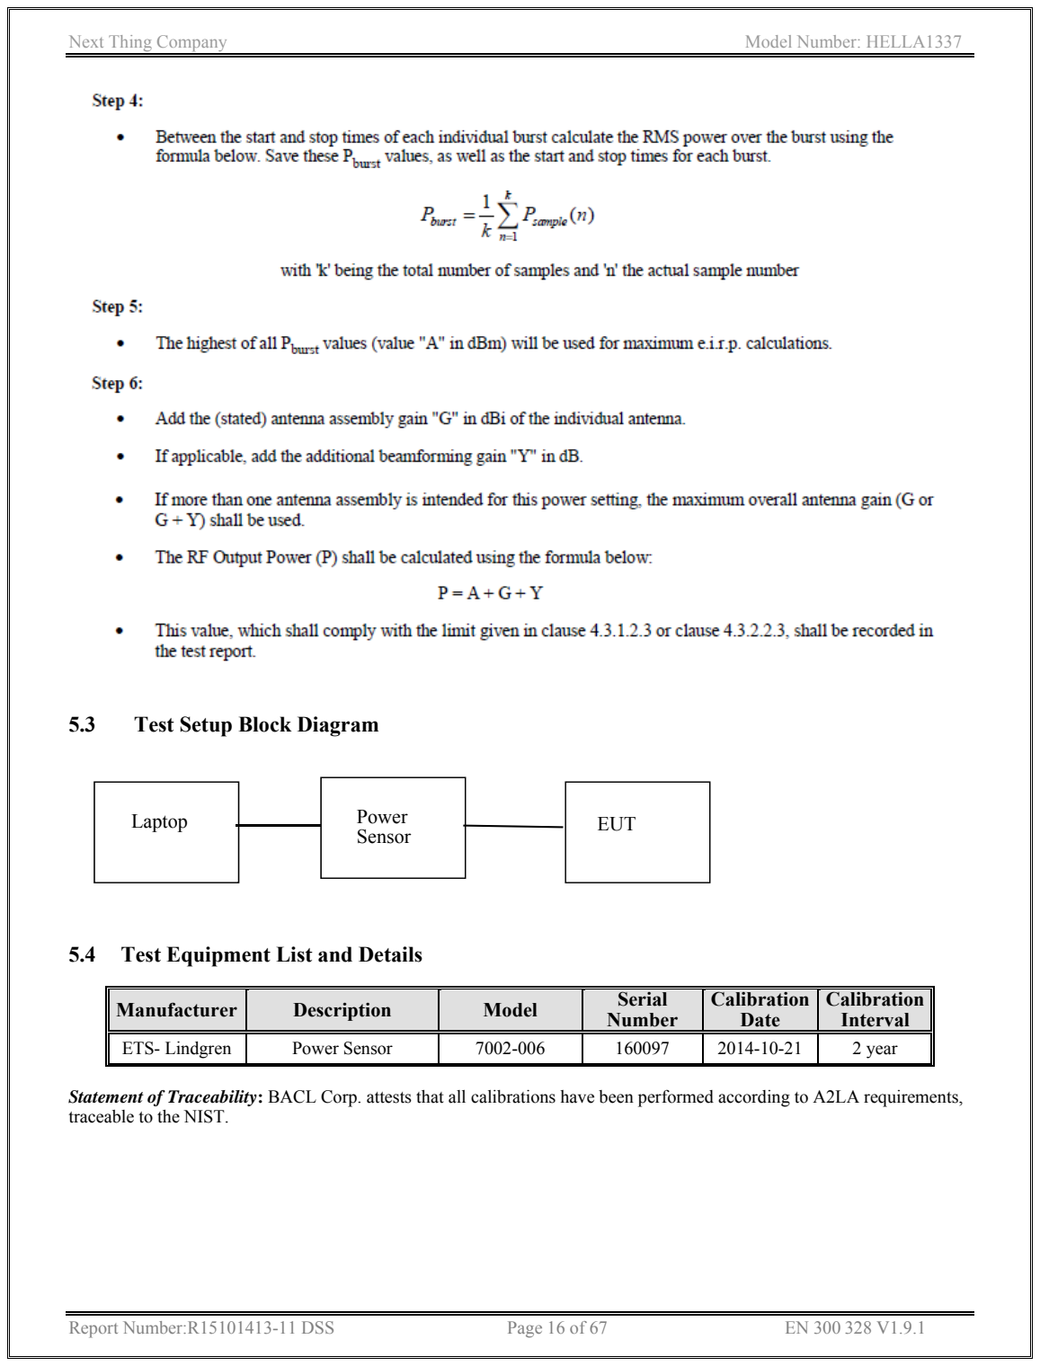
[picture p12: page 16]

Report Number:R15101413-11 DSS | Page 16 of 67 | EN 300 328 V1.9.1

### 5.3 Test Setup Block Diagram

### 5.4 Test Equipment List and Details

Manufacturer | Description | Model | Serial Number | Calibration Date | Calibration Interval
ETS- Lindgren | Power Sensor | 7002-006 | 160097 | 2014-10-21 | 2 year

Statement of Traceability: BACL Corp. attests that all calibrations have been performed according to A2LA requirements, traceable to the NIST.

Power
Sensor Laptop | EUT

Report Number:R15101413-11 DSS | Page 17 of 67 | EN 300 328 V1.9.1

### 5.5 Environmental Conditions

Temperature: | 21 °C
Relative Humidity: | 46 %
ATM Pressure: | 102kPa

Testing was performed by Jin Yang on 2015-10-23 on RF site.

### 5.6 Test Results

DH1

Frequency (MHz) | GFSK Power (dBm) | GFSK e.i.r.p (dBm) | Π/4-DQPSK Power (dBm) | Π/4-DQPSK e.i.r.p. (dBm) | 8PSK Power (dBm) | 8PSK e.i.r.p. (dBm) | Limit (dBm)
2402 | 5.75 | 8.25 | 5.03 | 7.53 | 5.01 | 7.51 | 20
2441 | 5.96 | 8.46 | 5.31 | 7.81 | 5.14 | 7.64 | 20
2480 | 5.88 | 8.38 | 5.12 | 7.62 | 5.17 | 7.67 | 20

DH3
Frequency (MHz) | GFSK Power (dBm) | GFSK e.i.r.p (dBm) | Π/4-DQPSK Power (dBm) | Π/4-DQPSK e.i.r.p. (dBm) | 8PSK Power (dBm) | 8PSK e.i.r.p. (dBm) | Limit (dBm)
2402 | 5.72 | 8.22 | 4.92 | 7.42 | 4.99 | 7.49 | 20
2441 | 5.89 | 8.39 | 5.12 | 7.62 | 5.08 | 7.58 | 20
2480 | 5.87 | 8.37 | 5.08 | 7.58 | 5.16 | 7.66 | 20

DH5
Frequency (MHz) | GFSK Power (dBm) | GFSK e.i.r.p (dBm) | Π/4-DQPSK Power (dBm) | Π/4-DQPSK e.i.r.p. (dBm) | 8PSK Power (dBm) | 8PSK e.i.r.p. (dBm) | Limit (dBm)
2402 | 5.51 | 8.01 | 4.83 | 7.33 | 5.02 | 7.52 | 20
2441 | 5.73 | 8.23 | 4.88 | 7.38 | 5.16 | 7.66 | 20
2480 | 5.78 | 8.28 | 4.98 | 7.48 | 4.97 | 7.47 | 20

Note: the antenna gain at 2.4GHz is 2.5dBi.

## 6 EN 300 328 §4.3.1.4 Dwell time, Minimum Frequency Occupation and Hopping Sequence

Report Number:R15101413-11 DSS | Page 18 of 67 | EN 300 328 V1.9.1

### 6.1 Applicable Standard

### 6.2 Measurement Procedures

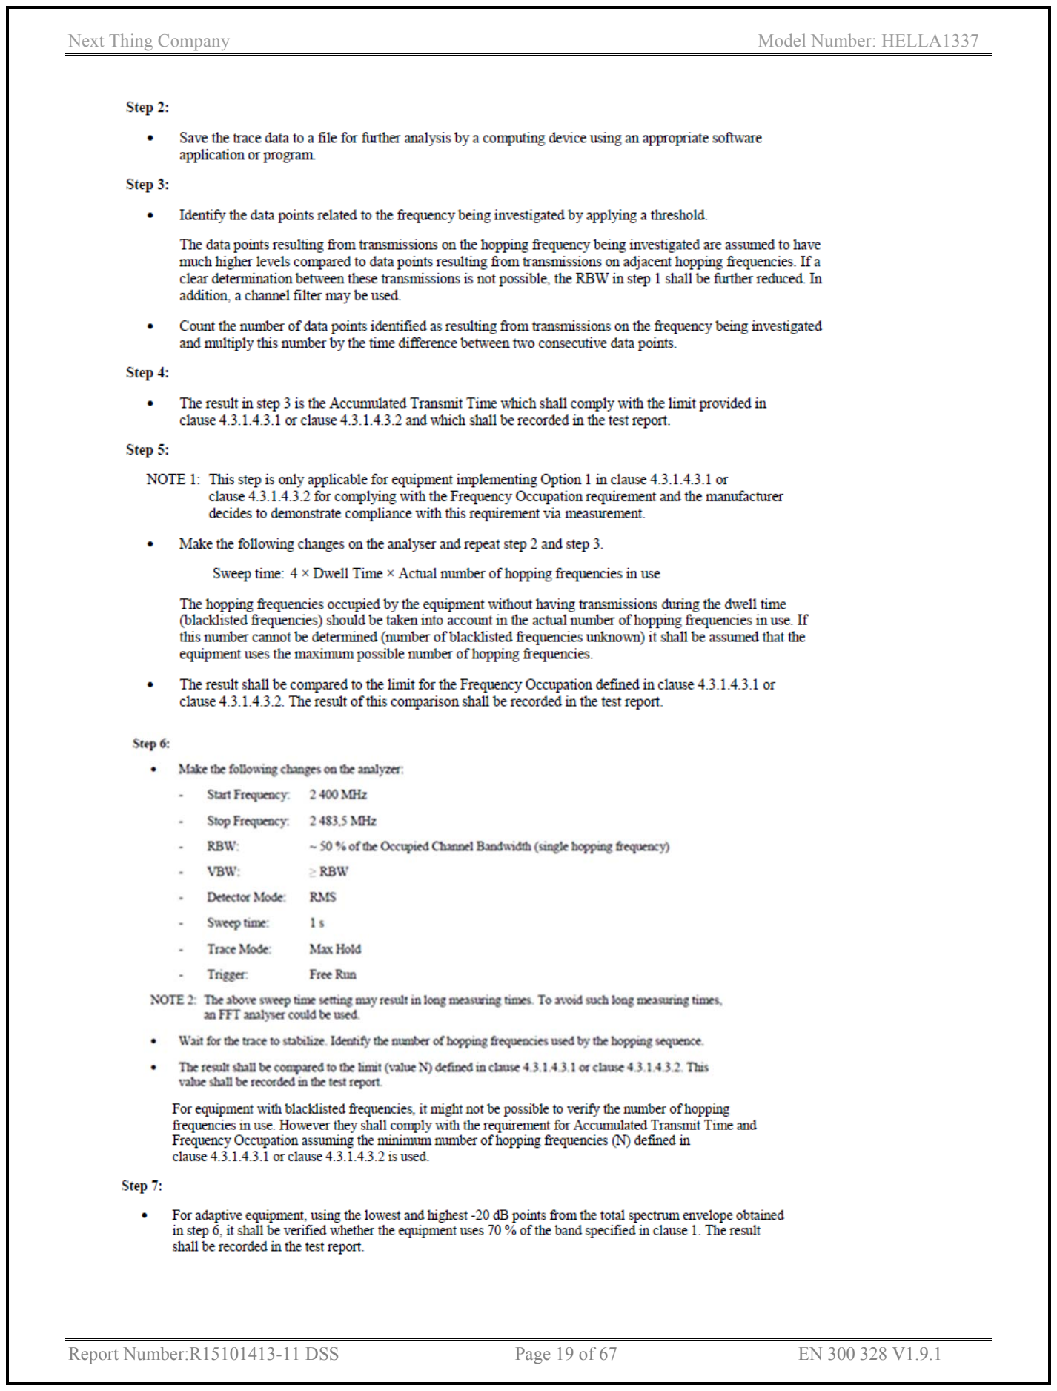
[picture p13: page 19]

Report Number:R15101413-11 DSS | Page 19 of 67 | EN 300 328 V1.9.1

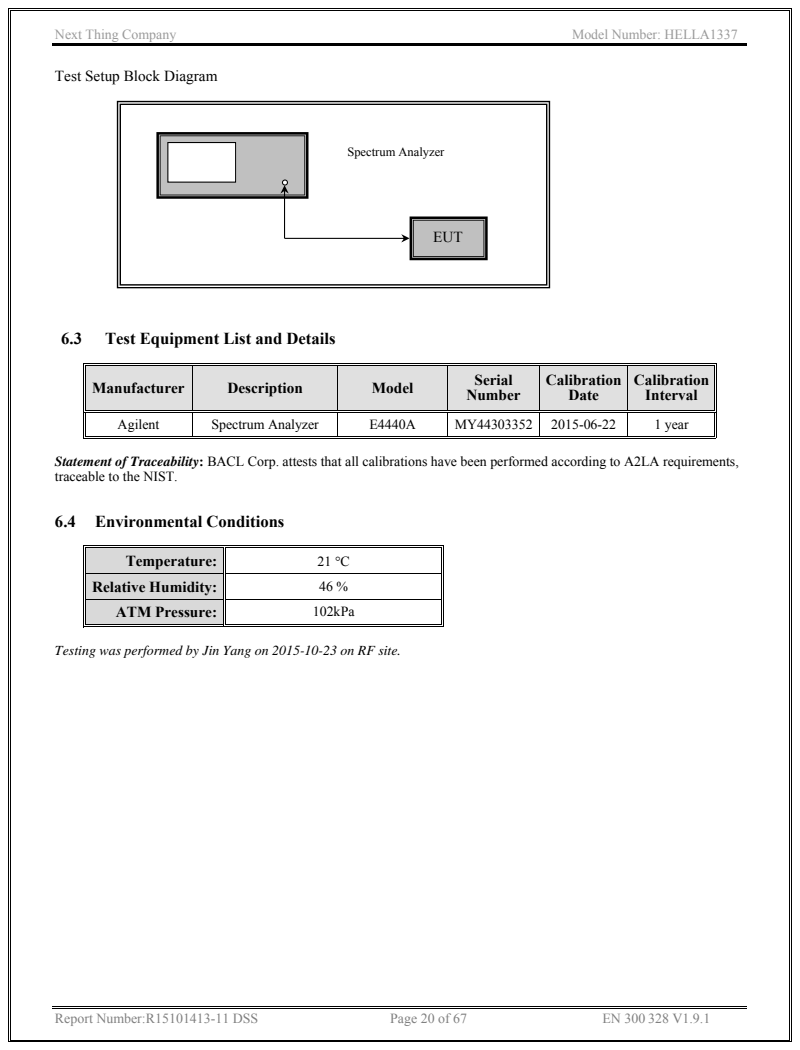
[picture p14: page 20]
Report Number:R15101413-11 DSS; Page 20 of 67; 6.4 Environmental Conditions; Spectrum Analyzer; EUT

Test Setup Block Diagram

6.3 Test Equipment List and Details

Manufacturer | Description | Model | Serial Number | Calibration Date | Calibration Interval

Agilent | Spectrum Analyzer | E4440A | MY44303352 | 2015-06-22 | 1 year

Statement of Traceability: BACL Corp. attests that all calibrations have been performed according to A2LA requirements,
traceable to the NIST.

Temperature: | 21 °C
Relative Humidity: | 46 %
ATM Pressure: | 102kPa

Testing was performed by Jin Yang on 2015-10-23 on RF site.

Report Number:R15101413-11 DSS | Page 21 of 67 | EN 300 328 V1.9.1

### 6.5 Test Results

Channel | Pulse Width
(ms)

Dwell time
(sec)

Limit
(sec) | Results

1-DH1
Low | 0.410 | 0.13 | 0.4 | Pass
Mid | 0.4117 | 0.13 | 0.4 | Pass
High | 0.4117 | 0.13 | 0.4 | Pass
2-DH1
Low | 0.420 | 0.13 | 0.4 | Pass
Mid | 0.420 | 0.13 | 0.4 | Pass
High | 0.420 | 0.13 | 0.4 | Pass
3-DH1
Low | 0.420 | 0.13 | 0.4 | Pass
Mid | 0.420 | 0.13 | 0.4 | Pass
High | 0.420 | 0.13 | 0.4 | Pass
1-DH3
Low | 1.675 | 0.27 | 0.4 | Pass
Mid | 1.675 | 0.27 | 0.4 | Pass
High | 1.680 | 0.27 | 0.4 | Pass
2-DH3
Low | 1.685 | 0.27 | 0.4 | Pass
Mid | 1.685 | 0.27 | 0.4 | Pass
High | 1.685 | 0.27 | 0.4 | Pass
3-DH3
Low | 1.685 | 0.27 | 0.4 | Pass
Mid | 1.685 | 0.27 | 0.4 | Pass
High | 1.685 | 0.27 | 0.4 | Pass
1-DH5
Low | 2.925 | 0.31 | 0.4 | Pass
Mid | 2.925 | 0.31 | 0.4 | Pass
High | 2.925 | 0.31 | 0.4 | Pass
2-DH5
Low | 2.933 | 0.31 | 0.4 | Pass
Mid | 2.933 | 0.31 | 0.4 | Pass
High | 2.933 | 0.31 | 0.4 | Pass
3-DH5
Low | 2.933 | 0.31 | 0.4 | Pass
Mid | 2.933 | 0.31 | 0.4 | Pass
High | 2.933 | 0.31 | 0.4 | Pass

Note: DH1: Dwell time = Pulse time*(1600/2/79)*31.6S DH3: Dwell time = Pulse time*(1600/4/79)*31.6S
DH5: Dwell time = Pulse time*(1600/6/79)*31.6S

## 7 EN 300 328 § 4.3.1.5 Hopping Frequency Separation

Report Number:R15101413-11 DSS | Page 22 of 67 | EN 300 328 V1.9.1

### 7.1 Applicable Standard

### 7.2 Measurement Procedures

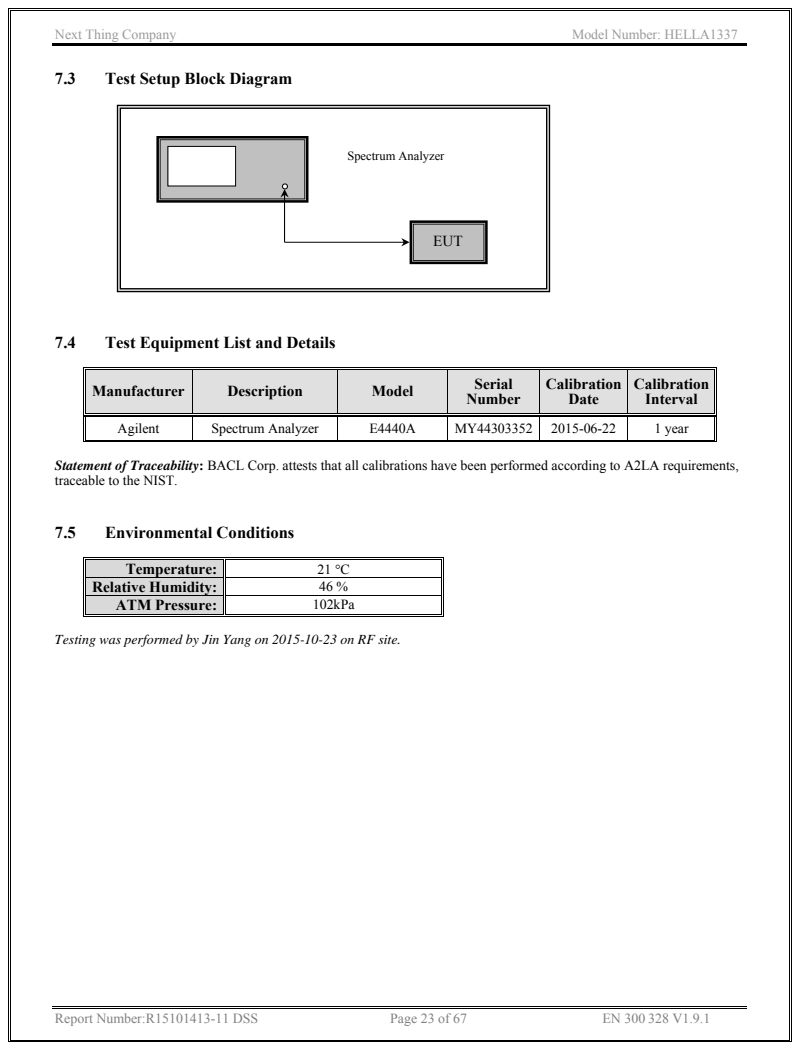
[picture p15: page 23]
Report Number:R15101413-11 DSS; Page 23 of 67; 7.5 Environmental Conditions; Spectrum Analyzer; EUT

7.3 Test Setup Block Diagram

7.4 Test Equipment List and Details

Manufacturer | Description | Model | Serial Number | Calibration Date | Calibration Interval

Agilent | Spectrum Analyzer | E4440A | MY44303352 | 2015-06-22 | 1 year

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

Temperature: | 21 °C
Relative Humidity: | 46 %
ATM Pressure: | 102kPa

Testing was performed by Jin Yang on 2015-10-23 on RF site.

Report Number:R15101413-11 DSS | Page 24 of 67 | EN 300 328 V1.9.1

### 7.6 Test Result

Mode | Channel | Channel Separation (MHz) | Limit (kHz)
GFSK | Low | 1.000 | >100
| Middle | 0.990 | >100
| High | 1.015 | >100
Π/4-DQPSK | Low | 0.995 | >100
| Middle | 1.010 | >100
| High | 0.990 | >100
8PSK | Low | 0.990 | >100
| Middle | 1.005 | >100
| High | 1.000 | >100

Please refer to the following plots.

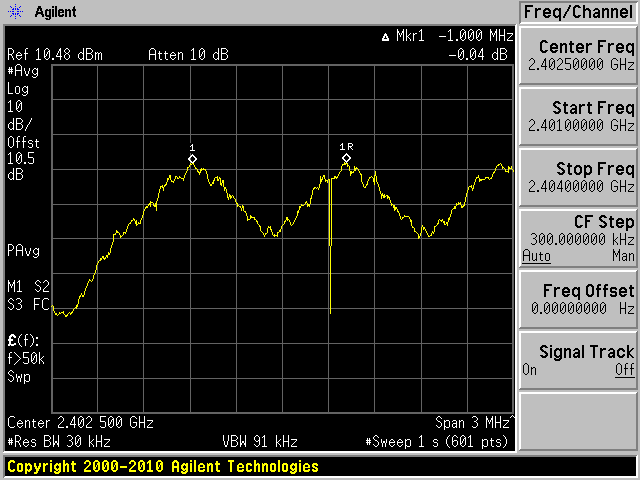
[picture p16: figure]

Report Number:R15101413-11 DSS | Page 25 of 67 | EN 300 328 V1.9.1

GFSK

Low Channel 2402 MHz | Middle Channel 2441 MHz

High Channel 2480 MHz


Report Number:R15101413-11 DSS | Page 26 of 67 | EN 300 328 V1.9.1

Π/4-DQPSK

Low Channel 2402 MHz | Middle Channel 2441 MHz

High Channel 2480 MHz


Report Number:R15101413-11 DSS | Page 27 of 67 | EN 300 328 V1.9.1

8PSK

Low Channel 2402 MHz | Middle Channel 2441 MHz

High Channel 2480 MHz

## 8 EN 300 328 §4.3.1.9 – TX Unwanted Emissions in the out of Band Domain

Report Number:R15101413-11 DSS | Page 28 of 67 | EN 300 328 V1.9.1

### 8.1 Applicable Standard

According to EN 300 328 V1.9.1, §4.3.1.9


Report Number:R15101413-11 DSS | Page 29 of 67 | EN 300 328 V1.9.1

### 8.2 Measurement Procedure

Report Number:R15101413-11 DSS; Page 30 of 67; Spectrum Analyzer; EUT

8.3 Test Setup Block Diagram

8.4 Test Equipment List and Details

Manufacturer | Description | Model | Serial Number | Calibration Date | Calibration Interval

Agilent | Spectrum Analyzer | E4440A | MY44303352 | 2015-06-22 | 1 year

Statement of Traceability: BACL attests that all calibrations have been performed per the A2LA requirements, traceable
to NIST.

Report Number:R15101413-11 DSS | Page 31 of 67 | EN 300 328 V1.9.1

### 8.5 Environmental Conditions

Temperature: | 21 °C
Relative Humidity: | 46 %
ATM Pressure: | 102kPa

Testing was performed by Jin Yang on 2015-10-23 on RF site.

### 8.6 Test Results

Channel Frequency
(MHz)

S.A
Amp.
(dBm/MHz)

Antenna
Gain
(dBi)

Limit e.i.r.p
(dBm/MHz) Results

GFSK

0 | 2398-2399 | -50.21 | 2.5 | -20 | Pass
0 | 2399-2400 | -37.38 | 2.5 | -10 | Pass
78 | 2483.5-2484.5 | -52.10 | 2.5 | -10 | Pass
78 | 2484.5-2485.5 | -52.61 | 2.5 | -20 | Pass

Π/4-DQPSK

0 | 2398-2399 | -45.16 | 2.5 | -20 | Pass
0 | 2399-2400 | -24.15 | 2.5 | -10 | Pass
78 | 2483.5-2484.5 | -51.09 | 2.5 | -10 | Pass
78 | 2484.5-2485.5 | -53.79 | 2.5 | -20 | Pass

8PSK

0 | 2398-2399 | -44.76 | 2.5 | -20 | Pass
0 | 2399-2400 | -23.54 | 2.5 | -10 | Pass
78 | 2483.5-2484.5 | -49.90 | 2.5 | -10 | Pass
78 | 2484.5-2485.5 | -52.93 | 2.5 | -20 | Pass

Report Number:R15101413-11 DSS | Page 32 of 67 | EN 300 328 V1.9.1

### GFSK

2398 MHz – 2399 MHz | 2399 MHz – 2400 MHz
2483.5 MHz – 2484.5 MHz | 2484.5 MHz – 2485.5 MHz

Report Number:R15101413-11 DSS | Page 33 of 67 | EN 300 328 V1.9.1

### Π/4-DQPSK

2398 MHz – 2399 MHz | 2399 MHz – 2400 MHz
2483.5 MHz – 2484.5 MHz | 2484.5 MHz – 2485.5 MHz


Report Number:R15101413-11 DSS | Page 34 of 67 | EN 300 328 V1.9.1

### 8PSK

2398 MHz – 2399 MHz | 2399 MHz – 2400 MHz
2483.5 MHz – 2484.5 MHz | 2484.5 MHz – 2485.5 MHz

Report Number:R15101413-11 DSS | Page 35 of 67 | EN 300 328 V1.9.1

## 9 EN 300 328 §4.3.1.10 – TX Unwanted emissions in the Spurious Domain

### 9.1 Applicable Standard

### 9.2 Measurement Uncertainty

All measurements involve certain levels of uncertainties, especially in field of EMC. The factors contributing to uncertainties are spectrum analyzer, cable loss, antenna factor calibration, antenna directivity, antenna factor variation with height, antenna phase center variation, antenna factor frequency interpolation, measurement distance variation, site imperfections, mismatch (average), and system repeatability.

Based on NIS 81, The Treatment of Uncertainty in EMC Measurements, the best estimate of the uncertainty of a radiation emissions measurement at BACL is +4.0 dB.

### 9.3 EUT Setup

The radiated emissions tests were performed in a shield room, using the setup accordance with the EN 300 328 V1.9.1. The specification used was the EN 300 328 V1.9.1 limits.

External I/O cables were draped along the edge of the test table and bundle when necessary.

Report Number:R15101413-11 DSS | Page 36 of 67 | EN 300 328 V1.9.1

### 9.4 Test Equipment List and Details

Manufacturer | Description | Model | Serial Number | Calibration Date | Calibration Interval
Agilent | Spectrum Analyzer | E4440A | MY44303352 | 2015-06-22 | 1 year
Sunol Science Corp | System Controller | SC99V | 122303-1 | N/R | N/R
Sunol Science Corp | Combination Antenna | JB3 | A020106-3 | 2015-07-11 | 1 year
Hewlett Packard | Pre-amplifier | 8447D | 2944A10187 | 2015-03-20 | 1 year
HP/ Agilant | Pre Amplifier | 8449B OPT HO2 | 3008A0113 | 2015-03-11 | 1year
Sunol | Horn antenna | DRH-118 | A052704 | 2015-03-09 | 1 year
EMCO | Antenna, Horn | 3115 | 9511-4627 | 2015-01-15 | 1 year
HP | Signal Generator | 83650B | 18485-91 | 2015-08-19 | 1 year
COM-POWER | Antenna, Dipole | AD-100 | 721033DB1, 721033DB2, 721033DB3, 721033DB4, | 2014-11-03 | 2 year

Statement of Traceability: BACL attests that all calibrations have been performed per the A2LA requirements, traceable to NIST.

### 9.5 Environmental Conditions

Temperature: | 24-26º C
Relative Humidity: | 45-48 %
ATM Pressure: | 101-102 kPa

Testing was performed by Jin Yang on 2015-10-28 at RF site and 5M3 chamber.

### 9.6 Measurement Procedure

For the radiated emissions test, the EUT and all support equipment power cords were connected to the AC floor outlet since the power supply used in the EUT did not provide an accessory power outlet.

Maximization procedure was performed on the six (6) highest emissions to ensure EUT compliance is with all installation combinations. All data was recorded in the peak detection mode. Quasi-peak readings was performed only when an emission was found to be marginal (within -4 dBµV of specification limits), and are distinguished with a "QP" in the data table.
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

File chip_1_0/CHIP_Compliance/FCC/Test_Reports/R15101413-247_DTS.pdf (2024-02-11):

Note: This test report is prepared for the customer shown above and for the device described herein. It may not be duplicated or used in part without prior written consent from Bay Area Compliance Laboratories Corp. This report must not be used by the customer to claim product certification, approval, or endorsement by A2LA*, NIST, or any agency of the Federal Government.
* This report may contain data that are not covered by the A2LA accreditation and are marked with an asterisk “*” (Rev.2)

# FCC PART 15, SUBPART C IC RSS-247, ISSUE 1, MAY 2015

# TEST AND MEASUREMENT REPORT

### For

# Next Thing Company

1940 Union Street, Ste. 32,

### Oakland, CA 94607, USA

## FCC ID: 2AF9F-HELLA1337 IC: 20863-HELLA1337

### Report Type:

Original Report

### Product Type: C.H.I.P Computer

Prepared By: Jin Yang
Test Engineer

Report Number: R15101413-247 DSS

Report Date: 2015-12-08

Reviewed By: Bo Li
RF Supervisor

Bay Area Compliance Laboratories Corp. 1274 Anvilwood Avenue,
Sunnyvale, CA 94089, USA
Tel: 1 (408) 732-9162
Fax: 1 (408) 732-9164

Next Thing Company | FCC ID: 2AF9F-HELLA1337; IC: 20863-HELLA1337
Report Number: R15101413-247 | Page 2 of 80 | FCC Part 15C/IC RSS-247 Test Report

## TABLE OF CONTENTS

Report Number: R15101413-247 | Page 3 of 80 | FCC Part 15C/IC RSS-247 Test Report

12 FCC §15.247(d) & IC RSS-247 §5.5, RSS-GEN §8.9 – Spurious Emissions at Antenna Terminals ... 61

Report Number: R15101413-247 | Page 4 of 80 | FCC Part 15C/IC RSS-247 Test Report

## DOCUMENT REVISION HISTORY

Revision Number | Report Number | Description of Revision | Date of Revision
0 | R15101413-247 | Original Report | 2015-12-08

Report Number: R15101413-247 | Page 5 of 80 | FCC Part 15C/IC RSS-247 Test Report

## 1 General Description

### 1.1 Product Description for Equipment Under Test (EUT)

This test and measurement report was prepared on behalf of Next Thing Company, and their product model: HELLA1337, FCC ID: 2AF9F-HELLA1337; IC: 20863-HELLA1337 or the “EUT” as referred to in this report. It is a module which contains 2.4 GHz 802.11b/g/n and Bluetooth, BLE capability.

### 1.2 Mechanical Description of EUT

The EUT measures approximately 60 mm (L) x 41 mm (W) x 10 mm (H) and weighs 23.5 g.

The test data gathered are from typical production sample, serial number: R15101413-01 assigned by BACL.

### 1.3 Objective

This report is prepared on behalf of Next Thing Company, in accordance with Part 2, Subpart J, and Part 15, Subparts B and C of the Federal Communication Commission’s rules and IC RSS-247 Issue 1, MAY 2015.

The objective is to determine compliance with FCC Part 15.247 and IC RSS-247 rules for Output Power, Antenna Requirements, 6 dB Bandwidth, Power spectral density, 100 kHz Bandwidth of Band Edges Measurement, Conducted and Radiated Spurious Emissions.

### 1.4 Related Submittal(s)/Grant(s)

FCC Part 15, Subpart C, Equipment DSS with FCC ID: 2AF9F-HELLA1337

### 1.5 Test Methodology

All measurements contained in this report were conducted in accordance with ANSI C63.10-2013, American National Standard of Procedures for Compliance Testing of Unlicensed Wireless Devices and FCC KDB 558074 D01 DTS Meas Guidance v03r03: Guidance for Performing Compliance Measurements on Digital Transmission Systems (DTS) Operating Under §15.247

### 1.6 Measurement Uncertainty

All measurements involve certain levels of uncertainties, especially in the field of EMC. The factors contributing to uncertainties are spectrum analyzer, cable loss, antenna factor calibration, antenna directivity, antenna factor variation with height, antenna phase center variation, antenna factor frequency interpolation, measurement distance variation, site imperfections, mismatch (average), and system repeatability.

Based on CISPR16-4-2:2011, The Treatment of Uncertainty in EMC Measurements, the values ranging from +2.0 dB for Conducted Emissions tests and +4.0 dB for Radiated Emissions tests are the most accurate estimates pertaining to uncertainty of EMC measurements at BACL Corp.

Report Number: R15101413-247 | Page 6 of 80 | FCC Part 15C/IC RSS-247 Test Report

### 1.7 Test Facility

Bay area compliance Laboratories Corp. (BACL) is:
1- An independent Commercial Test Laboratory accredited to ISO 17025: 2005 by A2LA, in the fields of: Electromagnetic Compatibility & Telecommunications covering Emissions, Immunity, Radio, RF Exposure, Safety and Telecom. This includes NEBS (Network Equipment Building System), Wireless RF, Telecommunications Terminal Equipment (TTE); Network Equipment; Information Technology Equipment (ITE); Medical Electrical Equipment; Industrial, Commercial, and Medical Test Equipment; Professional Audio and Video Equipment; Electronic (Digital) Products; Industrial and Scientific Instruments; Cabled Distribution Systems and Energy Efficiency Lighting.

2- An ENERGY STAR Recognized Laboratory, for the LM80 Testing, a wide variety of Luminares and Computers.

3- A NIST Designated Phase-I and Phase-II CAB including: ACMA (Australian Communication and Media Authority), BSMI (Bureau of Standards, Metrology and Inspection of Taiwan), IDA (Infocomm Development Authority of Singapore), IC(Industry Canada), Korea ( Ministry of Communications Radio Research Laboratory), NCC (Formerly DGT; Directorate General of Telecommunication of Chinese Taipei) OFTA (Office of the Telecommunications Authority of Hong Kong), Vietnam, VCCI - Voluntary Control Council for Interference of Japan and a designated EU CAB (Conformity Assessment Body) (Notified Body) for the EMC and R&TTE Directives.

4- A Product Certification Body accredited to ISO Guide 65: 1996 by A2LA to certify:
2. Radio Standards Specifications (RSS) in the Category I Equipment Standards List and All Broadcasting Technical Standards (BETS) in Category I Equipment Standards List for Industry Canada.
3. Radio Communication Equipment for Singapore.
4. Radio Equipment Specifications, GMDSS Marine Radio Equipment Specifications, and Fixed Network Equipment Specifications for Hong Kong.
5. Japan MIC Telecommunication Business Law (A1, A2) and Radio Law (B1, B2 and B3).
6. Audio/Video, Battery Charging Systems, Computers, Displays, Enterprise Servers, Imaging Equipment, Set-Top Boxes, Telephony, Televisions, Ceiling Fans, CFLs (Including GU24s),Decorative Light Strings, Integral LED Lamps, Luminaires, Residential Ventilating Fans.

The test site used by BACL Corp. to collect radiated and conducted emissions measurement data is located at its facility in Sunnyvale, California, USA.

The test site at BACL Corp. has been fully described in reports submitted to the Federal Communication Commission (FCC) and Voluntary Control Council for Interference (VCCI). The details of these reports have been found to be in compliance with the requirements of Section 2.948 of the FCC Rules on February 11 and December 10, 1997, and Article 8 of the VCCI regulations on December 25, 1997. The test site also complies with the test methods and procedures set forth in CISPR 22:2008 §10.4 for measurements below 1 GHz and §10.6 for measurements above 1 GHz as well as ANSI C63.10-2013, ANSI C63.4-2014, TIA/EIA-603 & CISPR 24:2010.

The Federal Communications Commission and Voluntary Control Council for Interference have the reports on file and they are listed under FCC registration number: 90464 and VCCI Registration No.: A-0027. The test site has been approved by the FCC and VCCI for public use and is listed in the FCC Public Access Link (PAL) database.

Additionally, BACL Corp. is an American Association for Laboratory Accreditation (A2LA) accredited laboratory (Lab Code 3297-02). The current scope of accreditations can be found at

http://www.a2la.org/scopepdf/3297-02.pdf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

Report Number: R15101413-247 | Page 7 of 80 | FCC Part 15C/IC RSS-247 Test Report

## 2 System Test Configuration

### 2.1 Justification

The EUT was configured for testing according to ANSI C63.10-2013 and FCC KDB 558074 D01 DTS Meas Guidance v03r03.

The EUT was tested in a testing mode to represent worst-case results during the final qualification test.

The worst-case data rates are determined to be as follows for each mode based upon investigation by measuring the average power, peak power and PPSD across all data rates bandwidths, and modulations.

### 2.2 EUT Exercise Software

The test utility used is UART Terminal (RS-232) provided by Next Thing, Co., the software was verified by Jin Yang to comply with the standard requirements being tested against.

### 2.3 Equipment Modifications

A SMA port was attached to the output signal before the antenna of the EUT to perform conducted measurements.

### 2.4 Local Support Equipment

Manufacturer | Description | Model
Acer | Laptop | ZHK

### 2.5 EUT Internal Configuration Details

Manufacturer | Description | Model
Realtek Semiconductor Corp | WIFI/BT Module | RTL8723BS
Allwinner Technology | Soc | R8

### 2.6 Support Equipment

Manufacturer | Description | Model
Apple | USB Power Adapter | A1357
Asian Power Devices, Inc | AC Adapter | WB-10E05FU

### 2.7 Interface Ports and Cabling

Cable Description | Length (m) | To | From
USB Cable | < 1 m | Laptop | EUT
RF Cable | < 1 m | EUT | PSA

Report Number: R15101413-247 | Page 8 of 80 | FCC Part 15C/IC RSS-247 Test Report

## 3 Summary of Test Results

Results reported relate only to the product tested.

FCC & IC Rules | Description of Test | Results
FCC §15.203 IC RSS-Gen §8.3 | Antenna Requirement | Compliant
FCC §15.207 IC RSS-Gen §8.8 | AC Line Conducted Emissions | Compliant
FCC §15.247(i) IC RSS-102 | RF Exposure | Compliant
FCC §15.247 (d) IC RSS-247 §5.5 | Spurious Emissions at Antenna Port | Compliant
FCC §15.205 IC RSS-Gen §8.10 | Restricted Bands | Compliant
FCC §15.209, §15.247 (d) IC RSS-247 §5.5, RSS-Gen §8.9 | Radiated Spurious Emissions | Compliant
FCC §15.247(a)(2) IC RSS-247 §5.2 | 6 dB&99% Emission Bandwidth | Compliant
FCC §15.247(b)(3) IC RSS-247 §5.4 | Maximum Peak Output Power | Compliant
FCC §15.247(d) IC RSS-247 §5.5 | 100 kHz Bandwidth of Frequency Band Edge | Compliant
FCC §15.247(e) IC RSS-247 §5.2 | Power Spectral Density | Compliant

Report Number: R15101413-247 | Page 9 of 80 | FCC Part 15C/IC RSS-247 Test Report

## 4 FCC §15.203 & IC RSS-Gen §8.3 – Antenna Requirements

### 4.1 Applicable Standards

According to FCC §15.203:

An intentional radiator shall be designed to ensure that no antenna other than that furnished by the responsible party shall be used with the device. The use of a permanently attached antenna or of an antenna that uses a unique coupling to the intentional radiator shall be considered sufficient to comply with the provisions of this Section. The manufacturer may design the unit so that a broken antenna can be replaced by the user, but the use of a standard antenna jack or electrical connector is prohibited.

And according to FCC §15.247 (b) (4), if transmitting antennas of directional gain greater than 6 dBi are used the power shall be reduced by the amount in dB that the directional gain of the antenna exceeds 6 dBi.

According to IC RSS-Gen §8.3: Transmitter Antenna

The applicant for equipment certification, as per RSP-100, must provide a list of all antenna types that may be used with the license-exempt transmitter, indicating the maximum permissible antenna gain (in dBi) and the required impedance for each antenna.

License-exempt transmitters that have received equipment certification may operate with different types of antennas. However, it is not permissible to exceed the maximum equivalent isotropically radiated power (e.i.r.p.) limits specified in the applicable standard (RSS) for the licence-exempt apparatus.

Testing shall be performed using the highest gain antenna of each combination of licence-exempt transmitter and antenna type, with the transmitter output power set at the maximum level. ⁹
When a measurement at the
antenna connector is used to determine RF output power, the effective gain of the device’s antenna shall be stated, based on a measurement or on data from the antenna manufacturer.

User manuals for transmitters equipped with detachable antennas shall also contain the following notice in a conspicuous location:

This radio transmitter (identify the device by certification number) has been approved by Industry Canada to operate with the antenna types listed below with the maximum permissible gain indicated. Antenna types not included in this list, having a gain greater than the maximum gain indicated for that type, are strictly prohibited for use with this device.

Immediately following the above notice, the manufacturer shall provide a list of all antenna types approved for use with the transmitter, indicating the maximum permissible antenna gain (in dBi).

### 4.2 Antenna Description

Antenna Type | Antenna Gain (dBi) @ 2.4 GHz
Chip Antenna | 2.5

Report Number: R15101413-247 | Page 10 of 80 | FCC Part 15C/IC RSS-247 Test Report

## 5 FCC §15.247(i) & IC RSS-102 – RF Exposure

### 5.1 Applicable Standards

According to FCC §15.247(i) and §1.1307(b)(1), systems operating under the provisions of this section shall be operated in a manner that ensures that the public is not exposed to radio frequency energy level in excess of the Commission’s guidelines.

Limits for General Population/Uncontrolled Exposure

Frequency
Range
(MHz)

Electric Field
Strength
(V/m)

Magnetic Field
Strength
(A/m)

Power Density
(mW/cm²
)

Averaging Time
(minutes)

Limits for General Population/Uncontrolled Exposure
0.3-1.34 | 614 | 1.63 | * (100) | 30
1.34-30 | 824/f | 2.19/f | * (180/f² ) | 30
30-300 | 27.5 | 0.073 | 0.2 | 30
300-1500 | / | / | f/1500 | 30
1500-100,000 | / | / | 1.0 | 30

f = frequency in MHz
* = Plane-wave equivalent power density
Before equipment certification is granted, the procedure of IC RSS-102 must be followed concerning the exposure of humans to RF field

According to IC RSS-102 Issue 5:

Report Number: R15101413-247 | Page 11 of 80 | FCC Part 15C/IC RSS-247 Test Report

### 5.2 MPE Prediction

Predication of MPE limit at a given distance, Equation from OET Bulletin 65, Edition 97-01

## S = PG/4πR²

Where: S = power density
P = power input to antenna
G = power gain of the antenna in the direction of interest relative to an isotropic radiator R = distance to the center of radiation of the antenna

### 5.3 MPE Results

### 2.4 GHz Wi-Fi

Maximum peak output power at antenna input terminal (dBm): 12.7 Maximum peak output power at antenna input terminal (mW): 18.621 Prediction distance (cm): 20 Prediction frequency (MHz): 2462 Maximum Antenna Gain, typical (dBi): 2.5 Maximum Antenna Gain (numeric): 1.778 Power density of prediction frequency at 20.0 cm (mW/cm² ): 0.0066
FCC MPE limit for uncontrolled exposure at prediction frequency (mW/cm²

): 1.0

The device is compliant with the requirement MPE limit for uncontrolled exposure. The maximum power density at the distance of 20 cm is 0.0066 mW/cm². Limit is 1.0 mW/cm²

BLE
Maximum peak output power at antenna input terminal (dBm): 4.28 Maximum peak output power at antenna input terminal (mW): 2.6792 Prediction distance (cm): 20 Prediction frequency (MHz): 2440 Maximum Antenna Gain, typical (dBi): 2.5 Maximum Antenna Gain (numeric): 1.778 Power density of prediction frequency at 20.0 cm (mW/cm² ): 0.00095
FCC MPE limit for uncontrolled exposure at prediction frequency (mW/cm²

): 1.0

The device is compliant with the requirement MPE limit for uncontrolled exposure. The maximum power density at the distance of 20 cm is 0.00095 mW/cm². Limit is 1.0 mW/cm²

RF exposure evaluation exemption for IC

2.4 GHz Wi-Fi: 12.7 + 2.5 dBi = 15.2 dBm < 1.31×10⁻²f

0.6834 = 2.7219 W = 34.3488 dBm

BLE: 4.28 + 2.5 dBi = 6.78 dBm < 1.31×10⁻²f

0.6834 = 2.7053 W = 34.32214 dBm

Therefore the RF exposure is not required.

Report Number: R15101413-247 | Page 12 of 80 | FCC Part 15C/IC RSS-247 Test Report

## 6 FCC §15.207 & IC RSS-Gen §8.8 – AC Line Conducted Emissions

### 6.1 Applicable Standards

As per FCC §15.207 and IC RSS-Gen §8.8 Conducted limits:

For an intentional radiator that is designed to be connected to the public utility (AC) power line, the radio frequency voltage that is conducted back onto the AC power line on any frequency or frequencies within the band 150 kHz to 30 MHz shall not exceed the limits in the following table, as measured using a 50 µH/50 ohms line impedance stabilization network (LISN). Compliance with the provisions of this paragraph shall be based on the measurement of the radio frequency voltage between each power line and ground at the power terminal. The lower limit applies at the boundary between the frequencies ranges.

Frequency of Emission (MHz) | Conducted Limit (dBuV)
Quasi-Peak | Average
0.15-0.5 | 66 to 56 Note1 | 56 to 46 Note2
0.5-5 | 56 | 46
5-30 | 60 | 50

Note1: Decreases with the logarithm of the frequency. Note2: A linear average detector is required
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

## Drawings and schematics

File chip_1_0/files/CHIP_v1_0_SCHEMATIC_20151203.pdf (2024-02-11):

# Schematics Index：

# P01: REVISION HISTORY

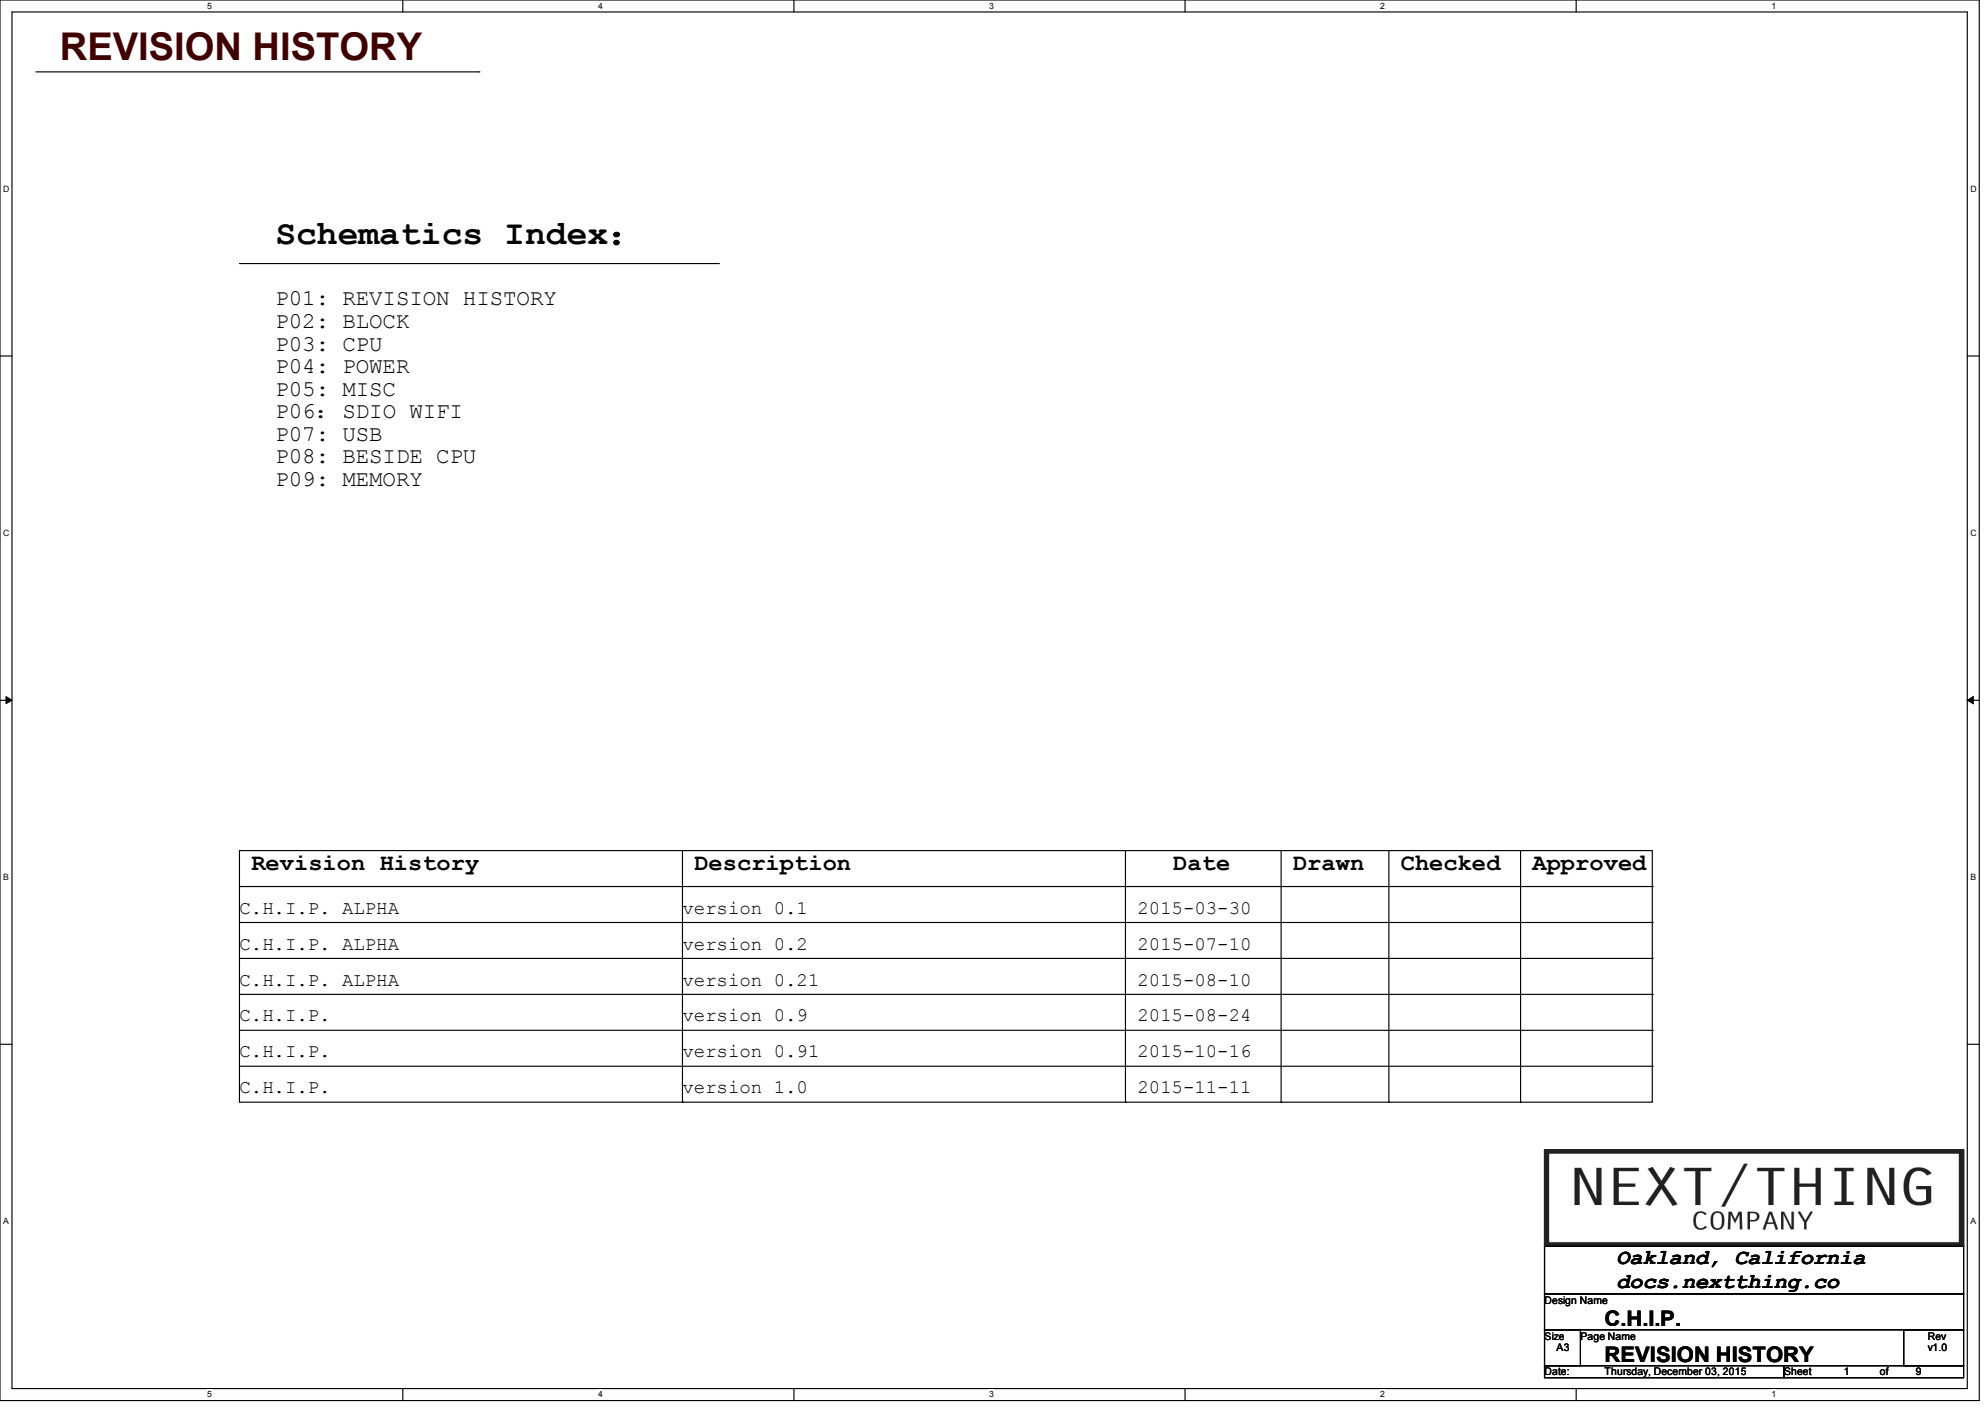
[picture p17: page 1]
Revision History; Description; Date; Drawn; Checked; Approved; P02: BLOCK P03: CPU P04: POWER P05: MISC P06：SDIO WIFI; P07: USB P08: BESIDE CPU P09: MEMORY; REVISION HISTORY; C.H.I.P. ALPHA; version 0.1; version 0.2; version 0.21; version 0.9; version 0.91; version 1.0; Design Name; Size; Page Name; Rev; Date:; Sheet; Thursday, December 03, 2015

Oakland, California
docs.nextthing.co

# BATT

# DCIN

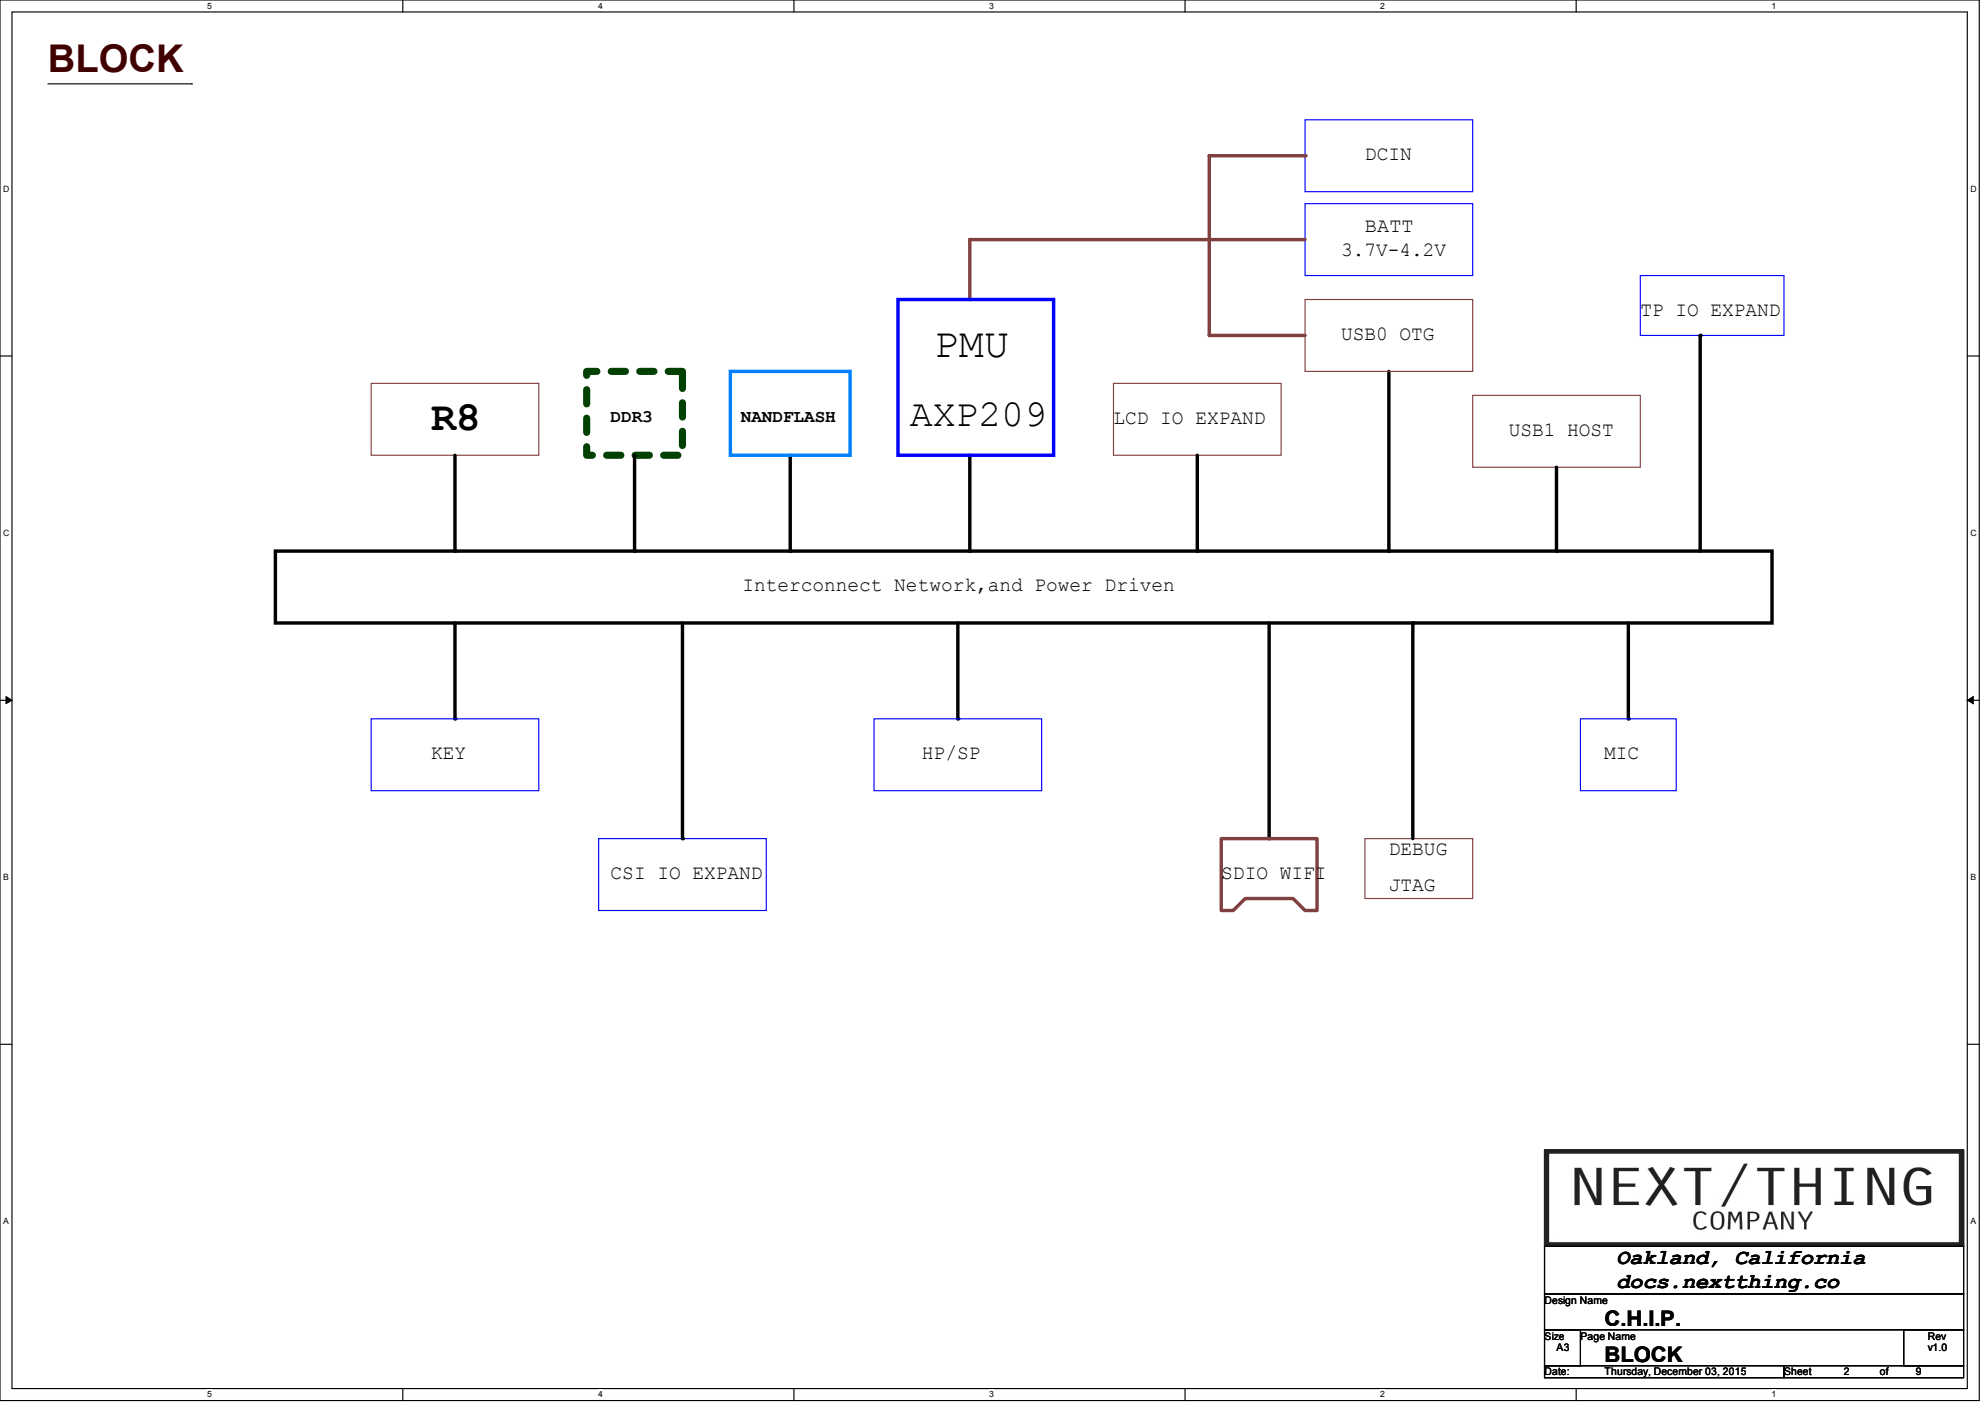
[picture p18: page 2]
SDIO WIFI; USB0 OTG; DEBUG; JTAG; KEY; PMU; AXP209; MIC; BLOCK; NANDFLASH; USB1 HOST R8; DDR3; Thursday, December 03, 2015

TP IO EXPAND

LCD IO EXPAND

Interconnect Network,and Power Driven

CSI IO EXPAND

Oakland, California
docs.nextthing.co

# CPU

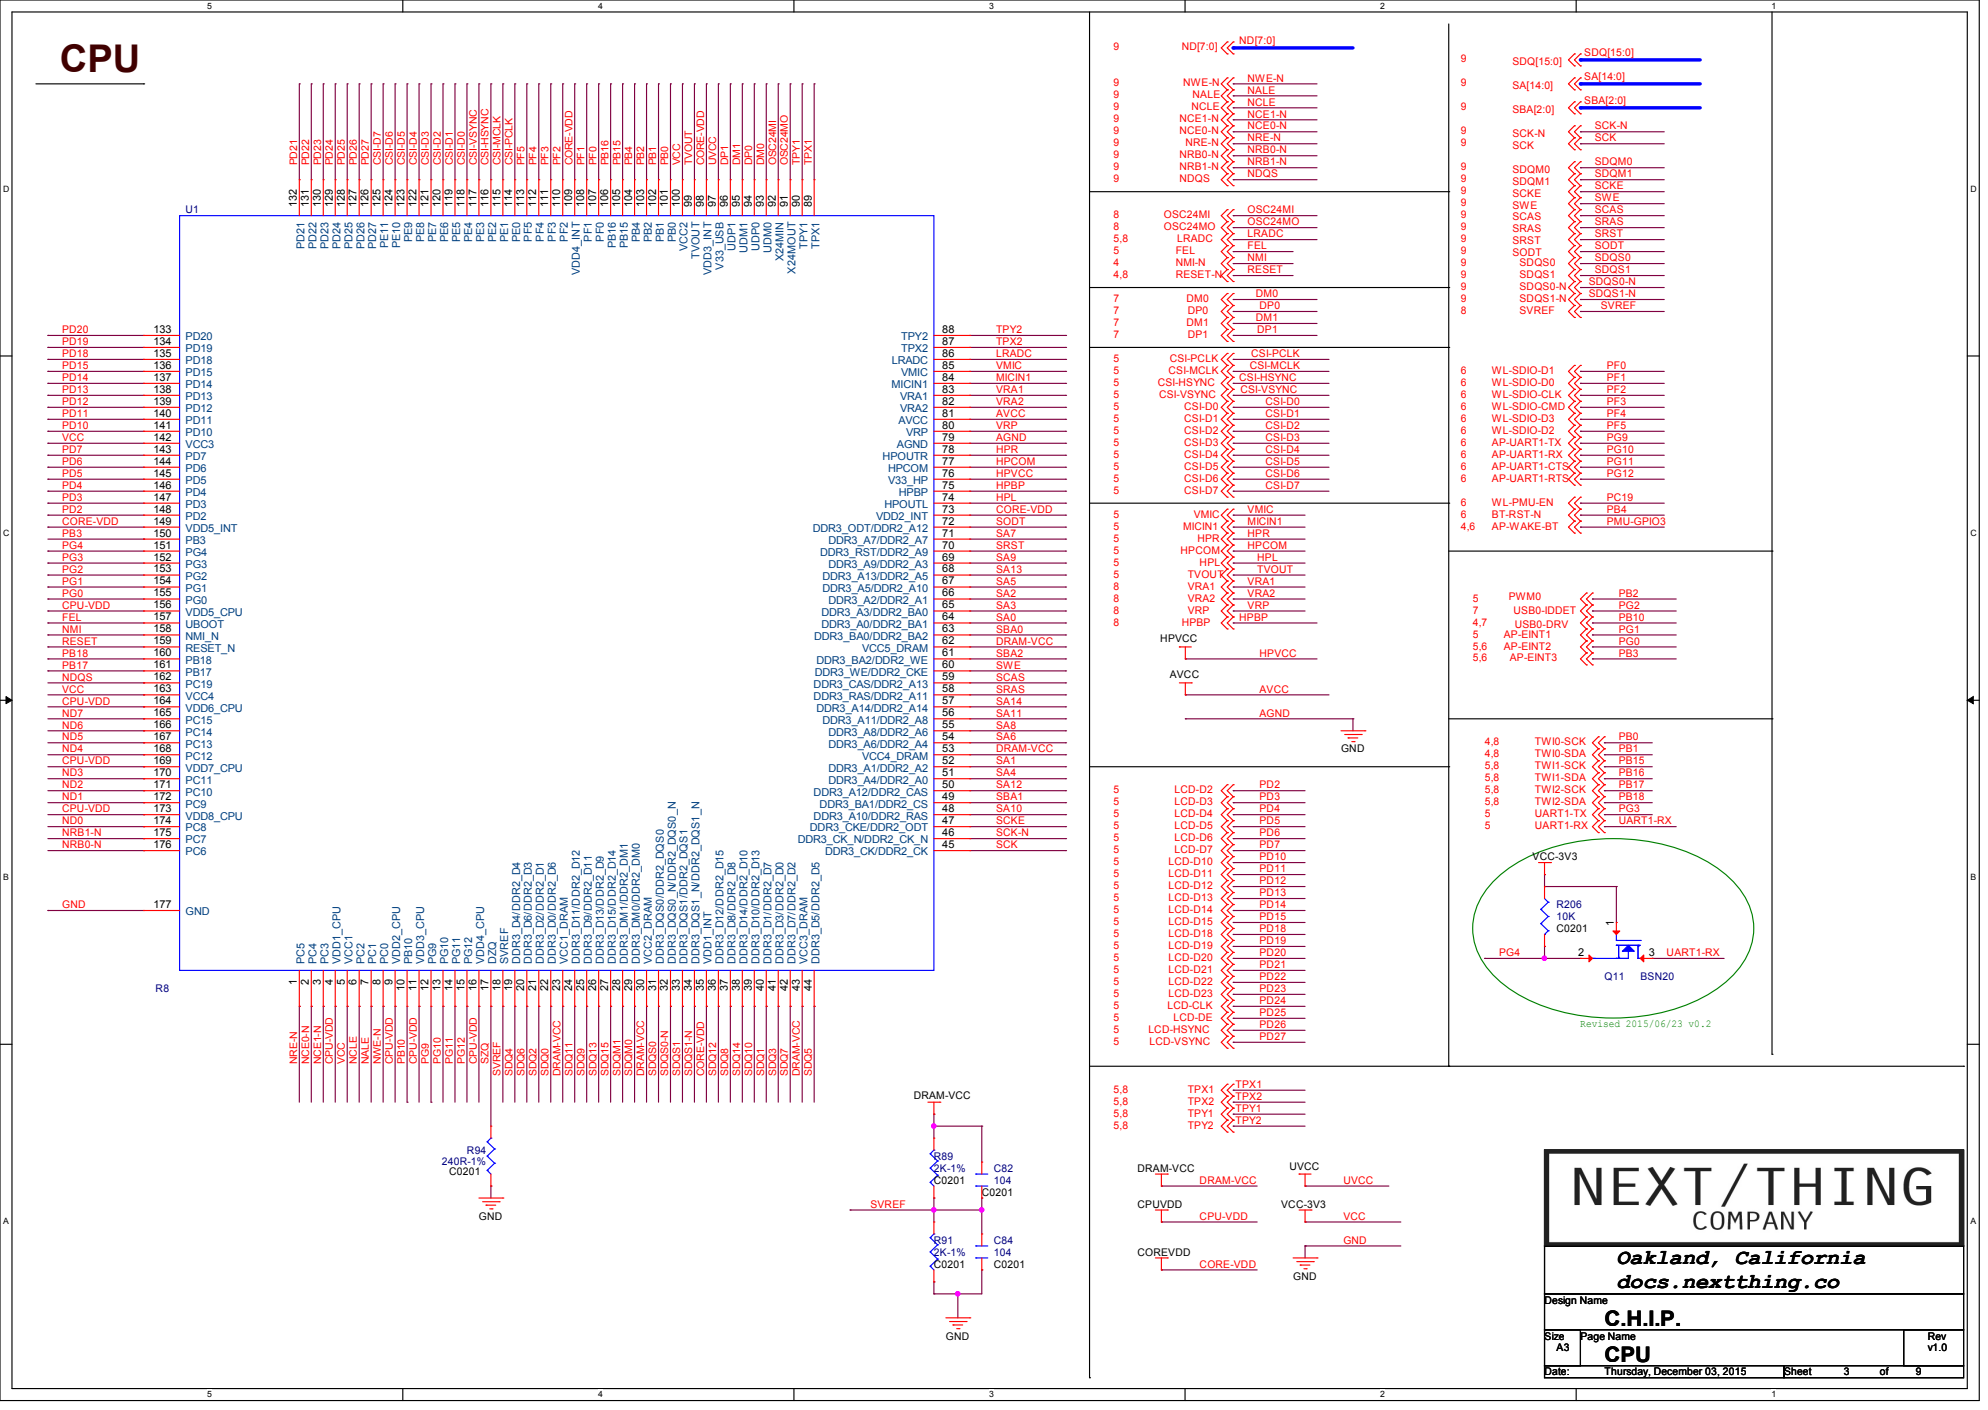
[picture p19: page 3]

# POWER/PMU

# IPSOUT TO 5V FOR SYS

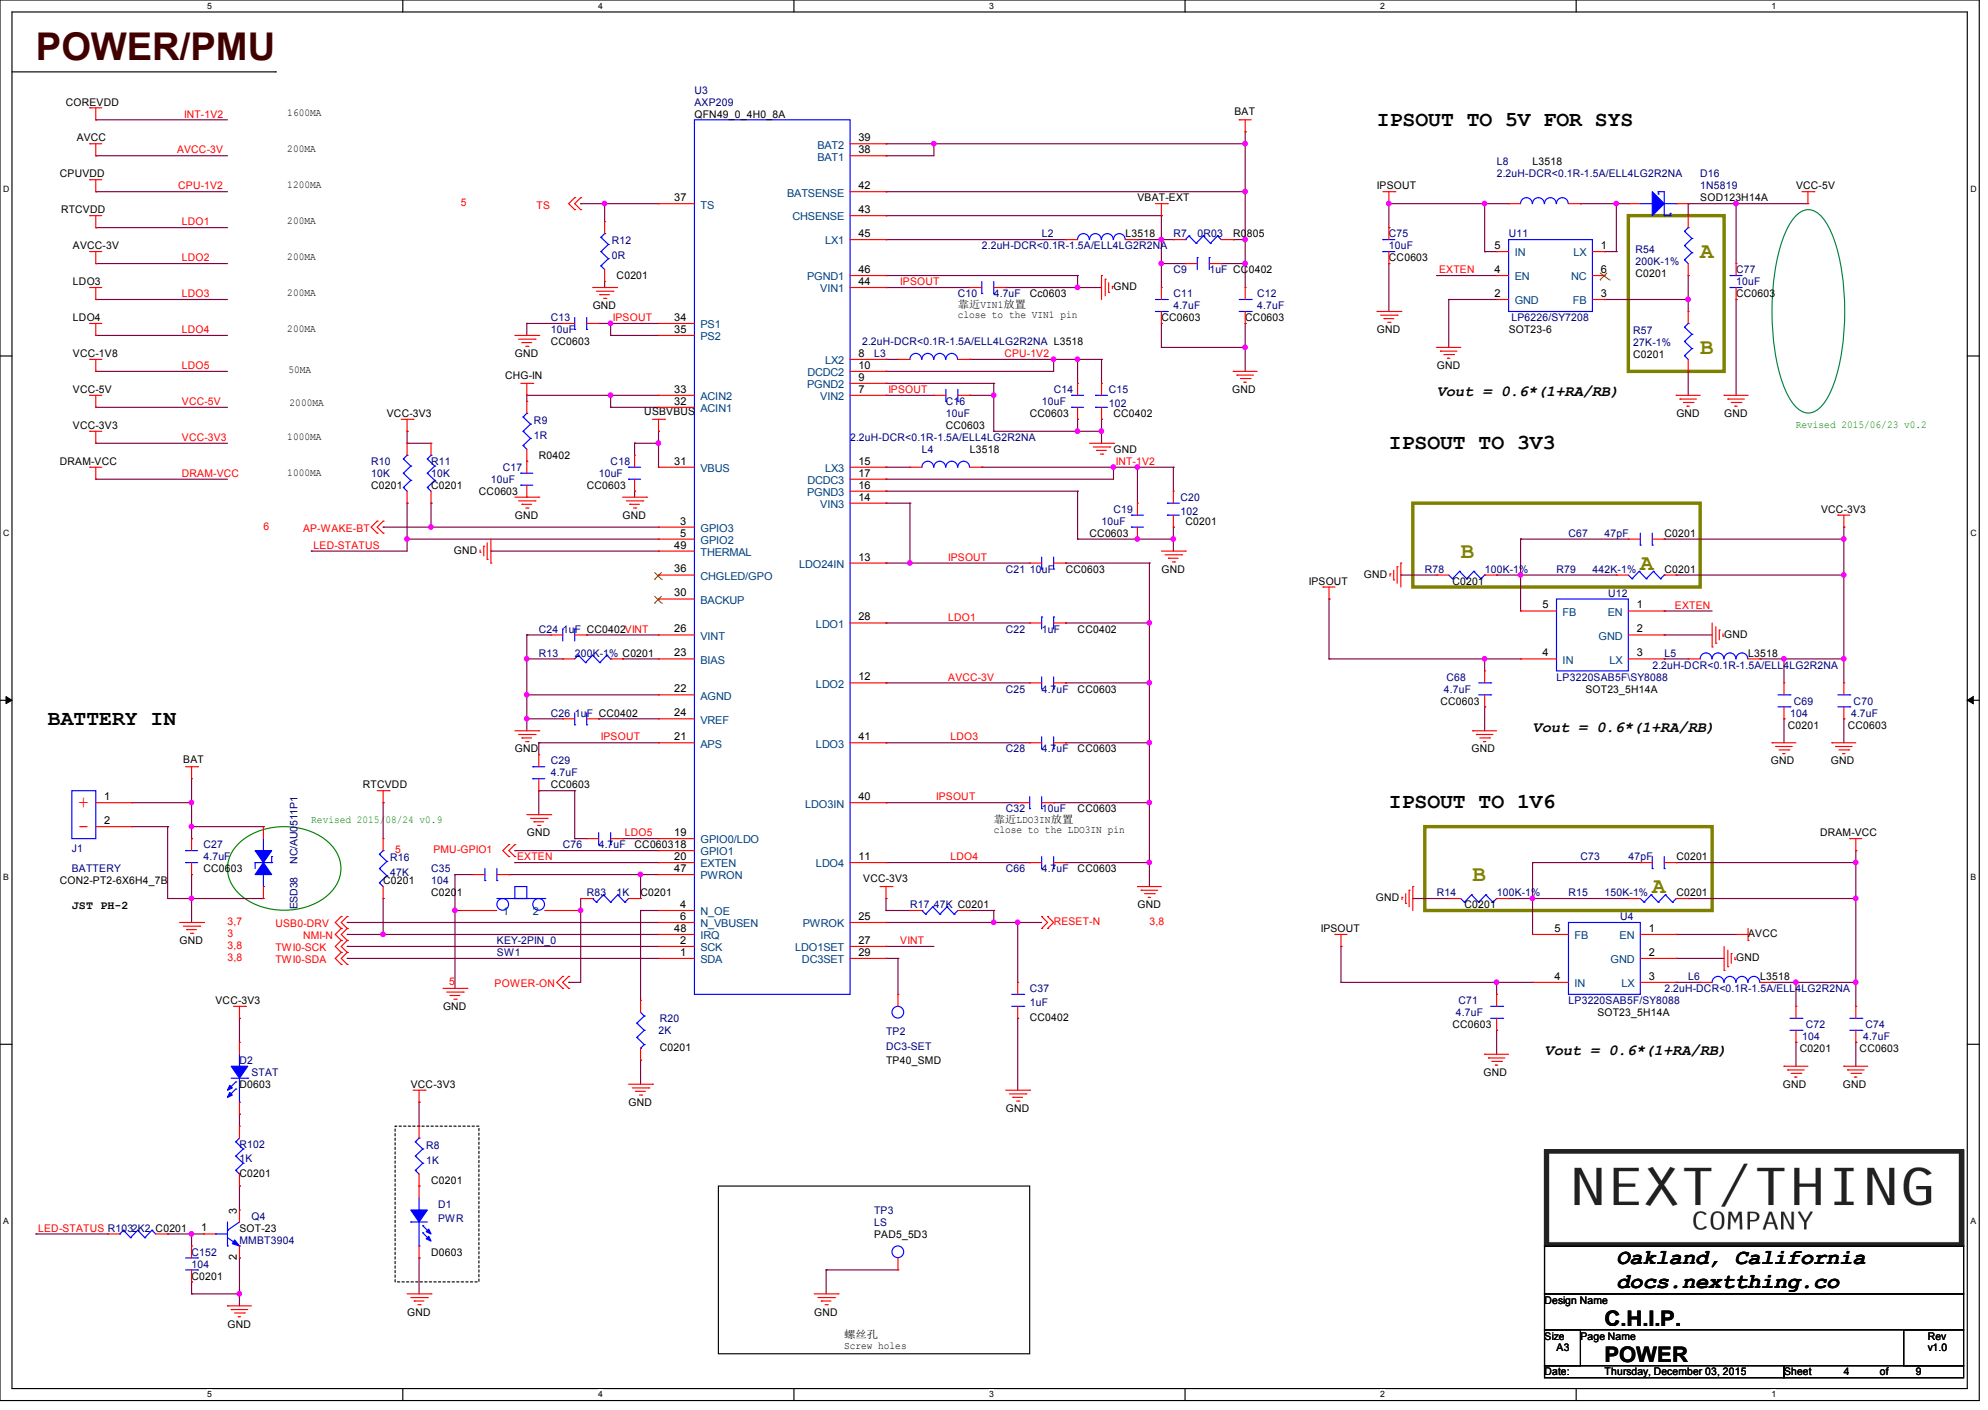
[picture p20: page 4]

靠近VIN1放置
close to the VIN1 pin

靠近LDO3IN放置
close to the LDO3IN pin

# MISC

## Note:

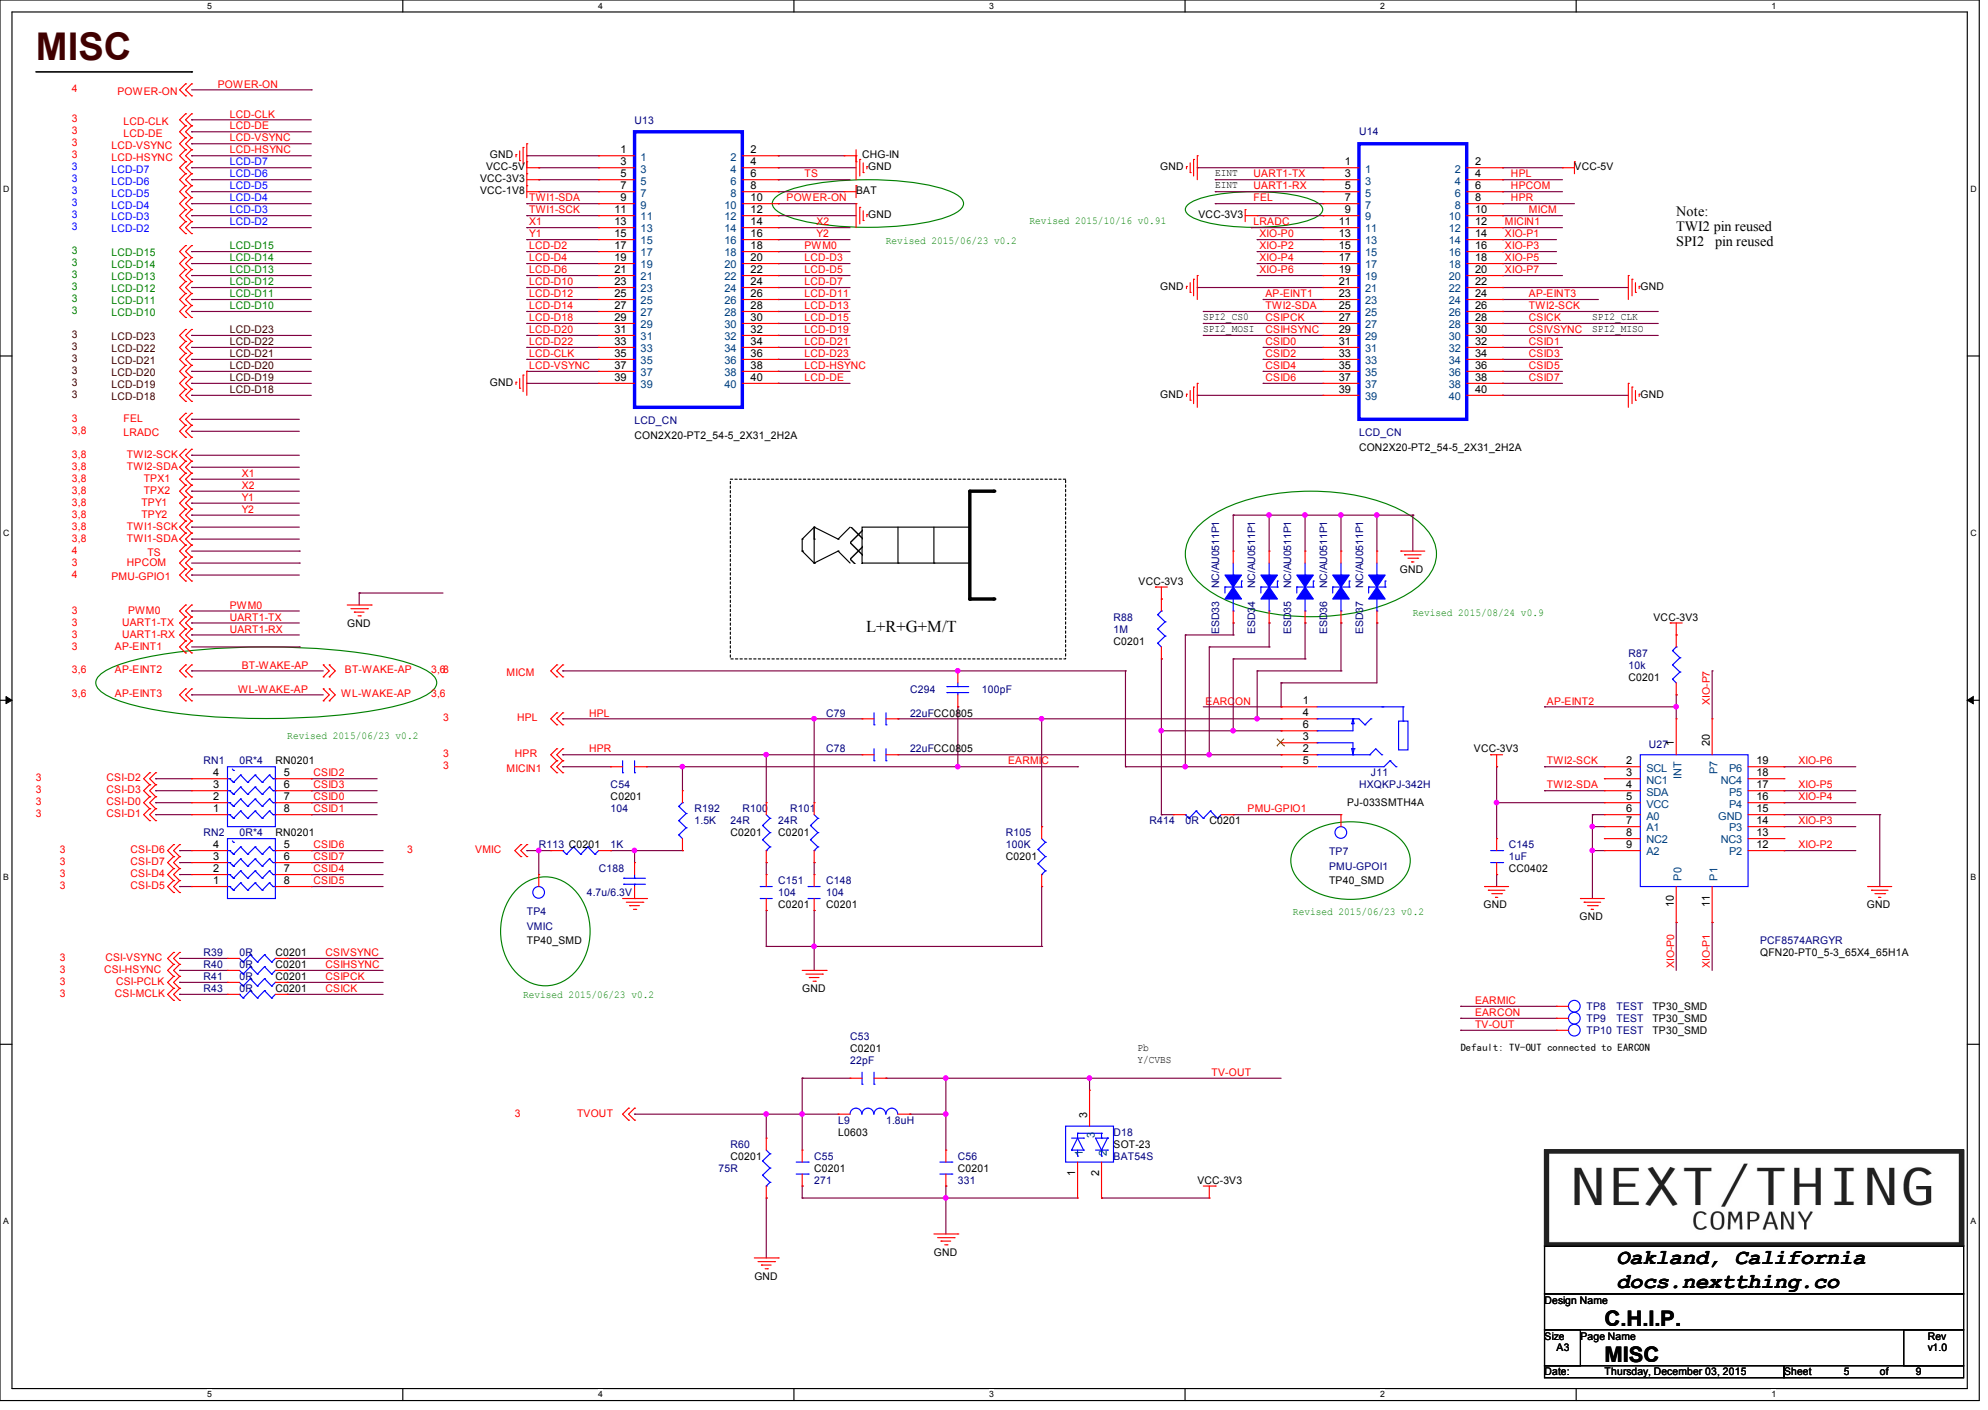
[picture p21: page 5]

EARMIC | | 6

Default: TV-OUT connected to EARCON

A

B

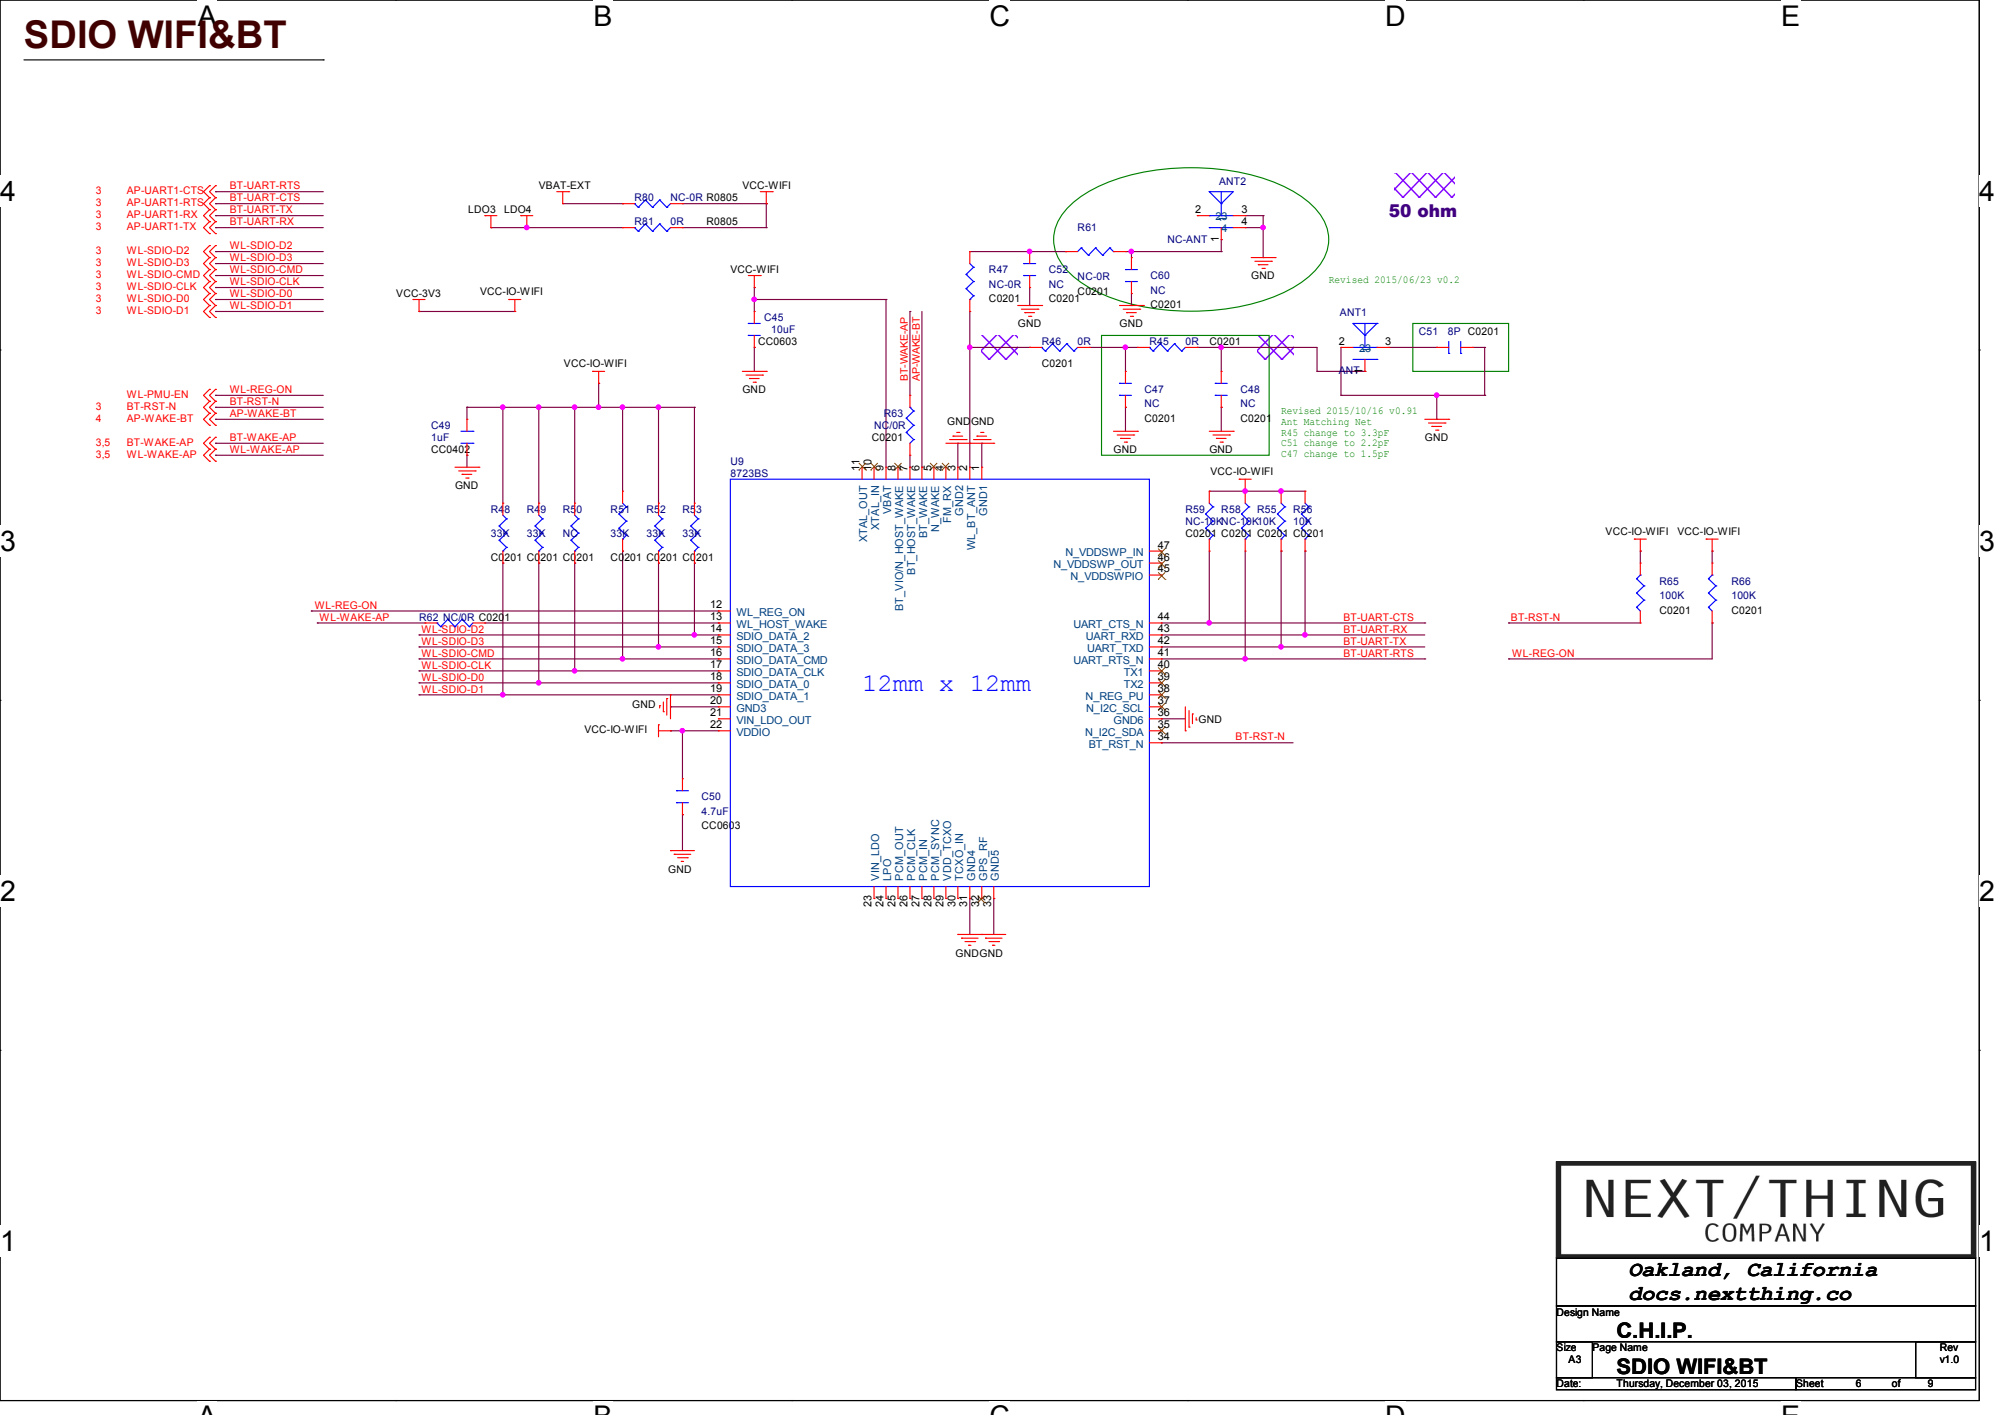
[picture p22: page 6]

VCC-IO-WIFI

# USB

# USB

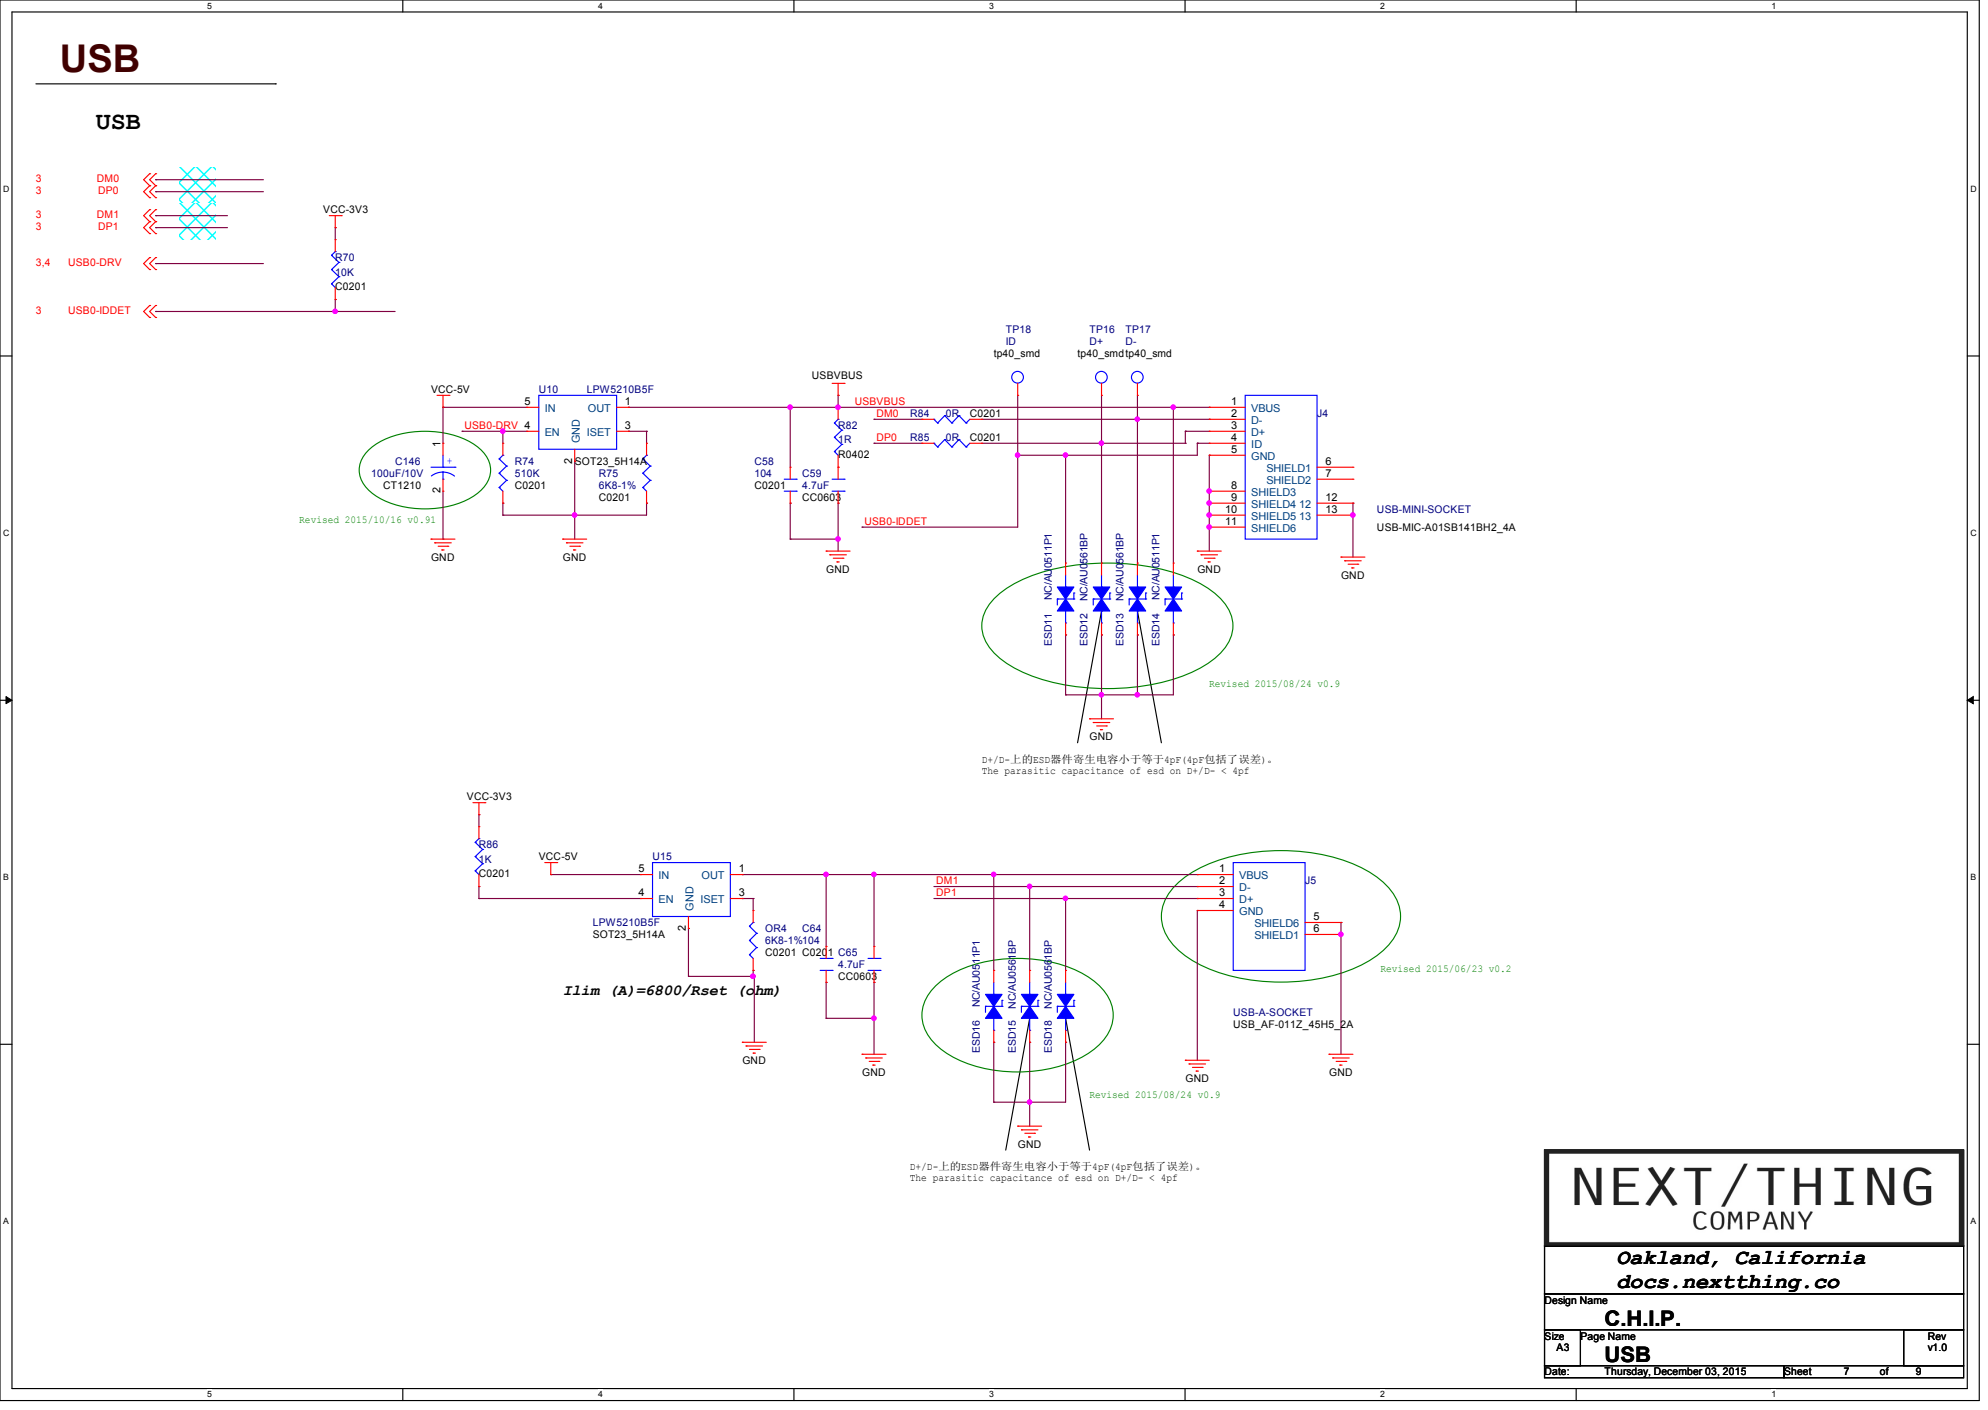
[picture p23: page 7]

D+/D-上的ESD器件寄生电容小于等于4pF(4pF包括了误差)。
The parasitic capacitance of esd on D+/D- < 4pf

# DRAM

# PIO-INTFACE

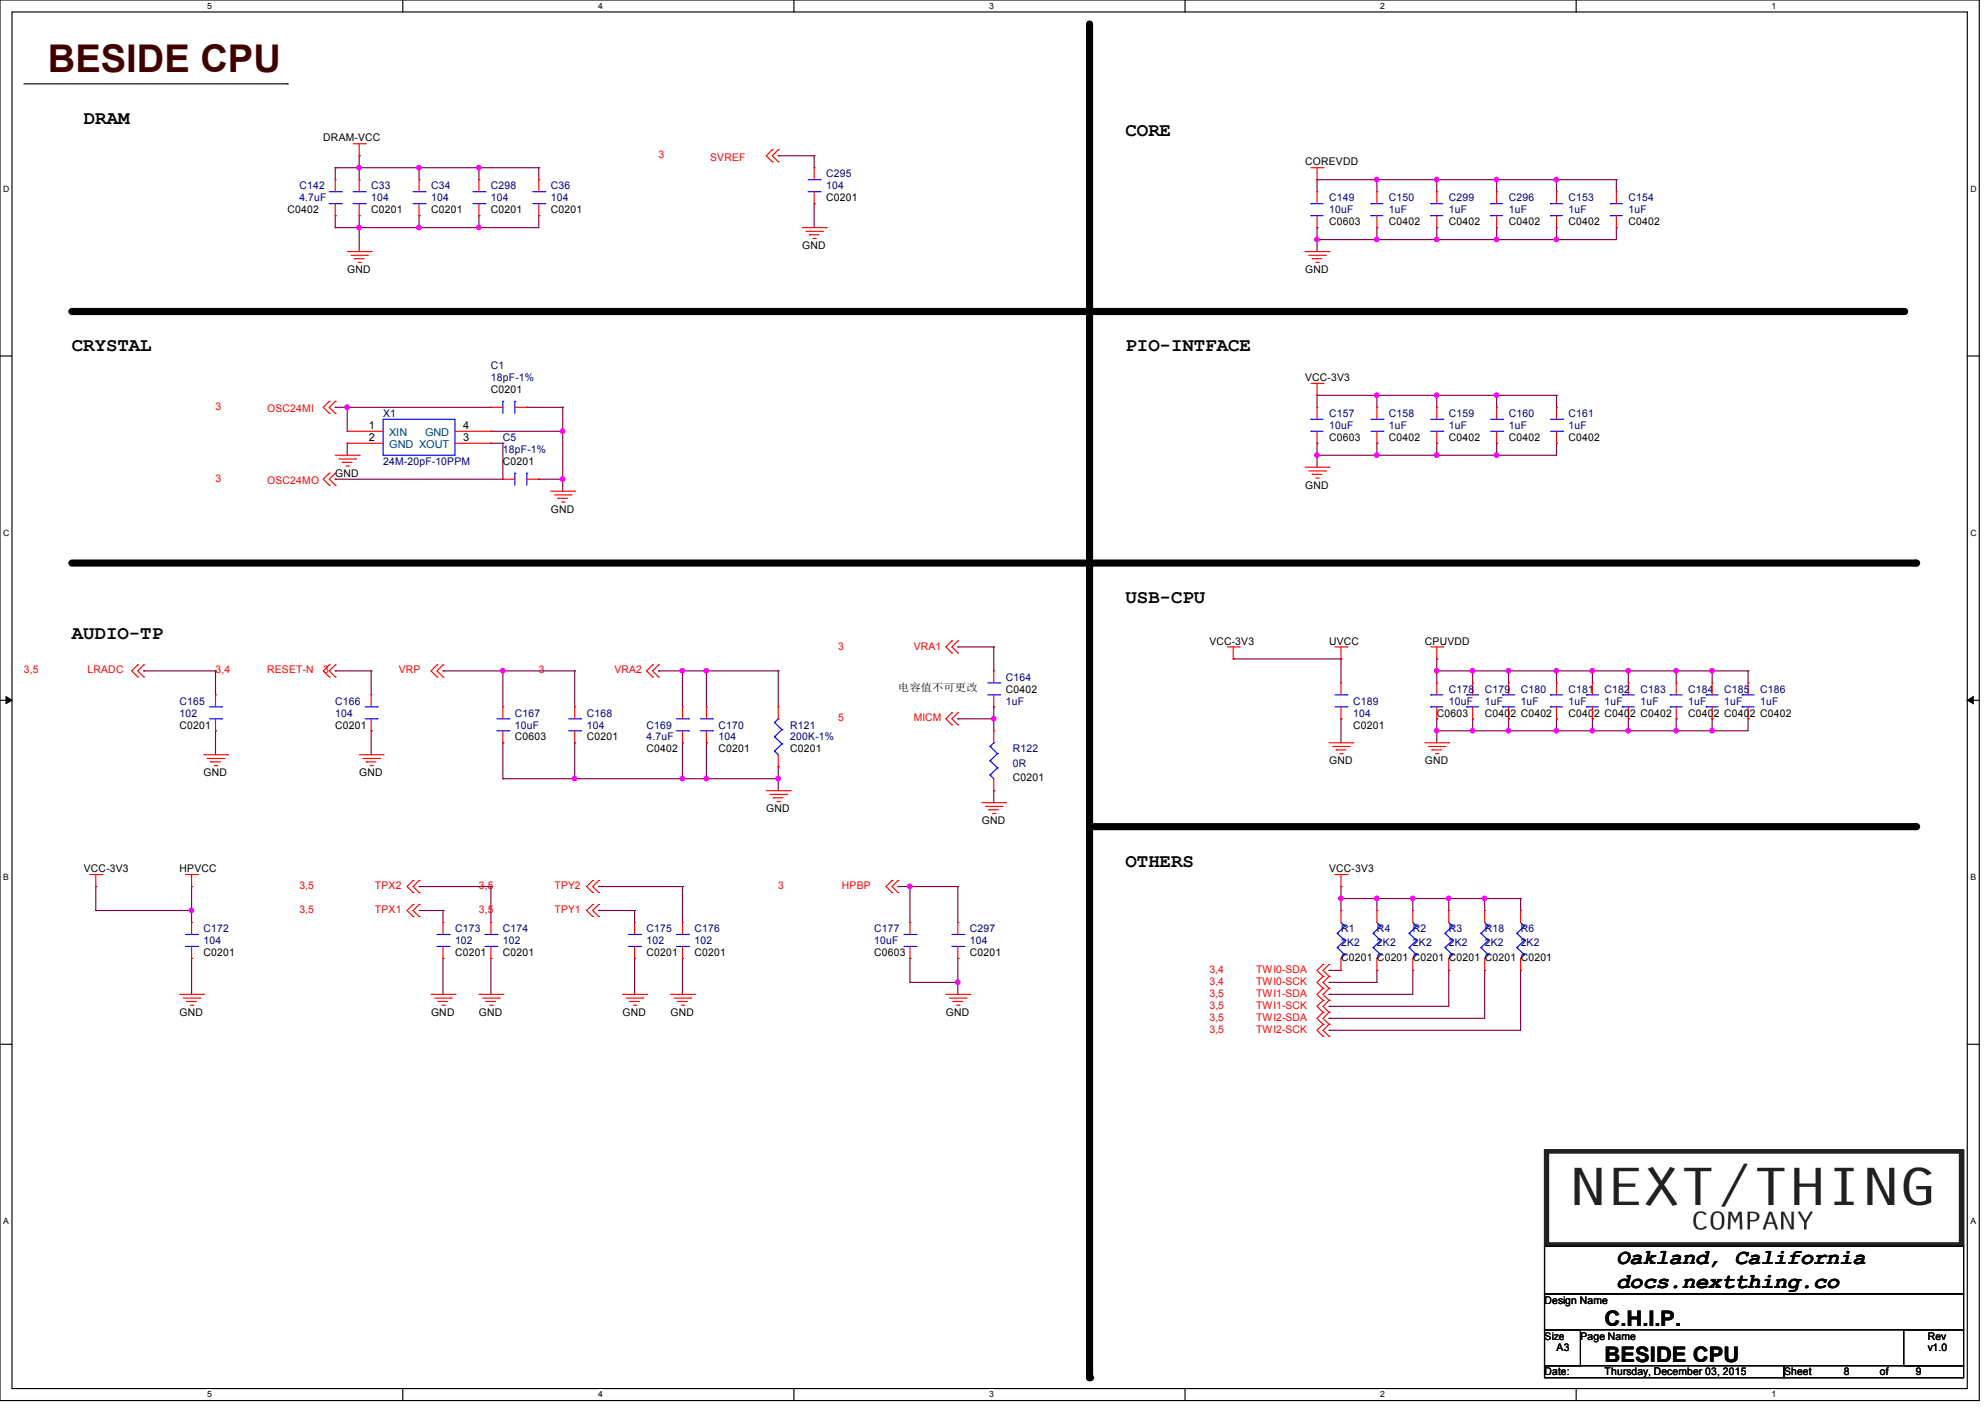
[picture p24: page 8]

# MEMORY

DDR3 | NAND

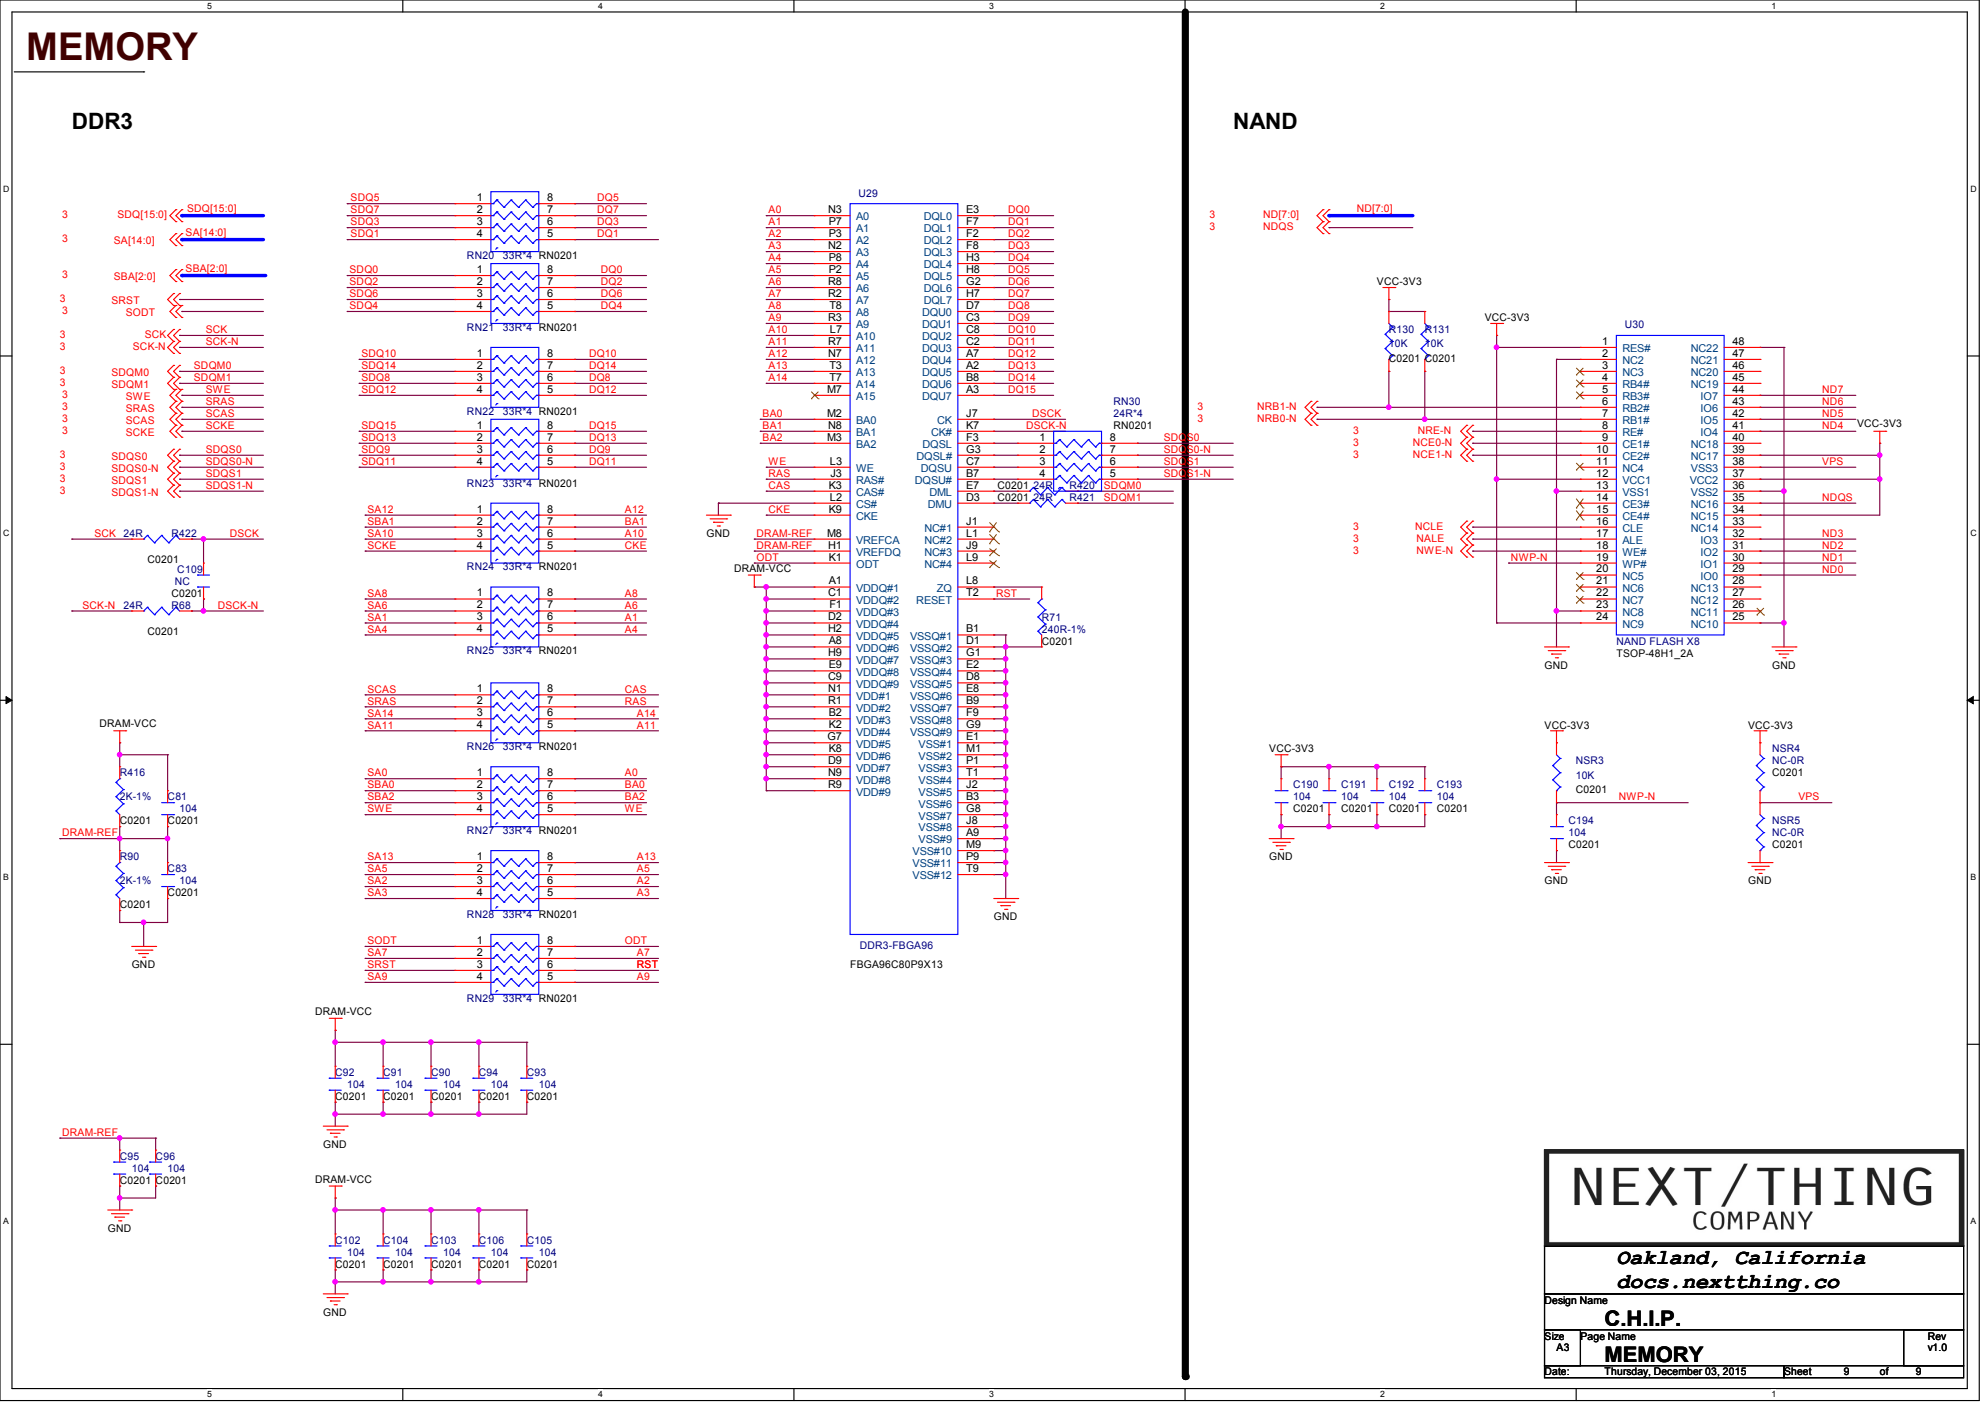
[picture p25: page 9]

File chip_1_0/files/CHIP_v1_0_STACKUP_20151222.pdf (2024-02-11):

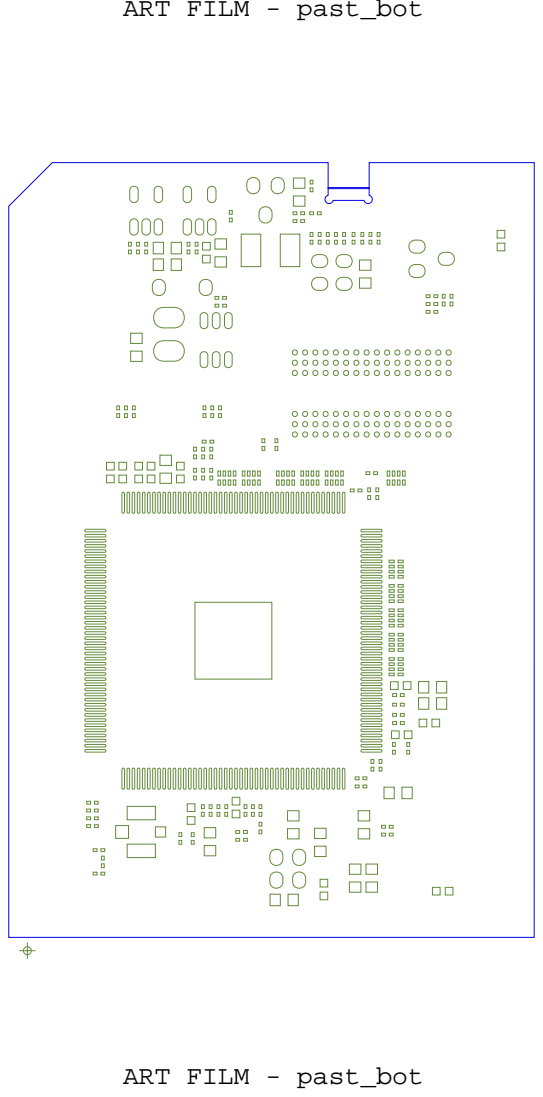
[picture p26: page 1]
ART FILM - past_bot

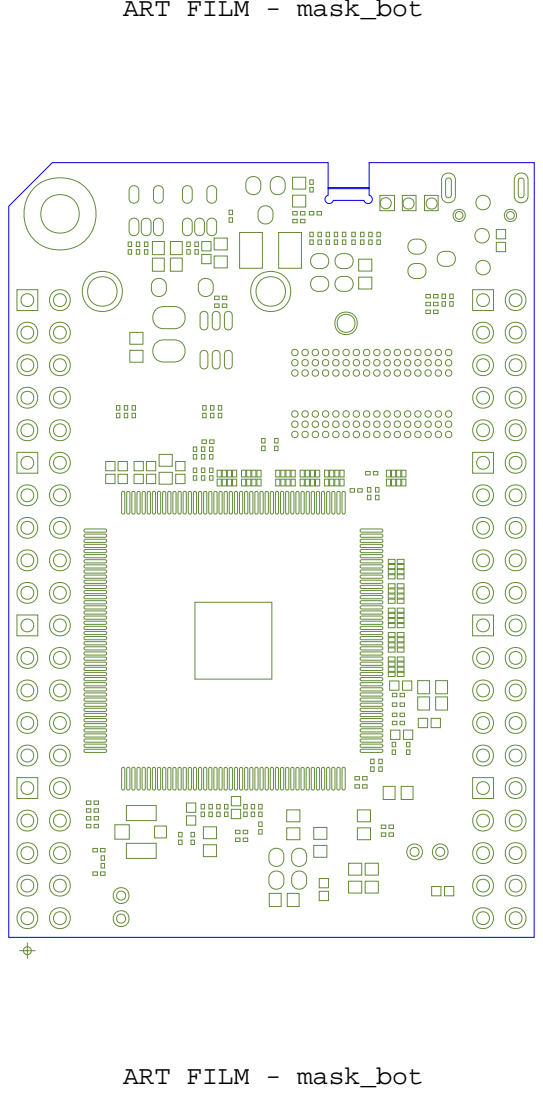
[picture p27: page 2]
ART FILM - mask_bot

## ALL UNITS ARE IN MILS

## DRILL CHART: TOP to BOTTOM

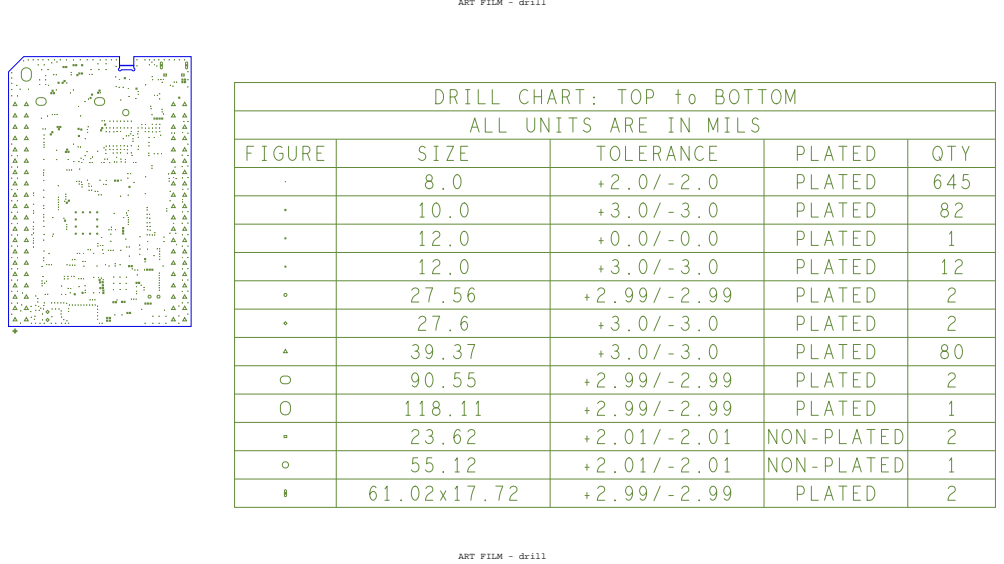
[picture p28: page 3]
QTY 645 82 1 12 2 2 80 2 1 2 1 2; PLATED PLATED PLATED PLATED PLATED PLATED PLATED PLATED PLATED PLATED; PLATED; NON-PLATED NON-PLATED; TOLERANCE +2.0/-2.0 +3.0/-3.0 +0.0/-0.0 +3.0/-3.0; SIZE; FIGURE

ART FILM - drill


ART FILM - gnd

ART FILM - silk_top; STAT; PWR; BAT; FCC ID: 2AF9F-HELLA1337


ART FILM - bottom

ART FILM - mask_top

ART FILM - past_top

ART FILM - silk_bot

mic tv v1.0 BAT GND

CC-BY-SA NEXTTHING.CO


ART FILM - top


ART FILM - vcc

ART FILM - in1

ART FILM - in2

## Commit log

2024-02-11 Initial version
    [CHIP_v1_0.dsn, CHIP_v1_0_BOM_20220330.xls]
2024-04-20 Add first-pass files
    [01 REVISION HISTORY-SchDoc.sch, 01 REVISION HISTORY.SchDoc, 02 BLOCK-SchDoc.sch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]
2024-04-24 Add altium render
    [CHIP.PrjPcb]
2024-04-26 Add ARM comparison table

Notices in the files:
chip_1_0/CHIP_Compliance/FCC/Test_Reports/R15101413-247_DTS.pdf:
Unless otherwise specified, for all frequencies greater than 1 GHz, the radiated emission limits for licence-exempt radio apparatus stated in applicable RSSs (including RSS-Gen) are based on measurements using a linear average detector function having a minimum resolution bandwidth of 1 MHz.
